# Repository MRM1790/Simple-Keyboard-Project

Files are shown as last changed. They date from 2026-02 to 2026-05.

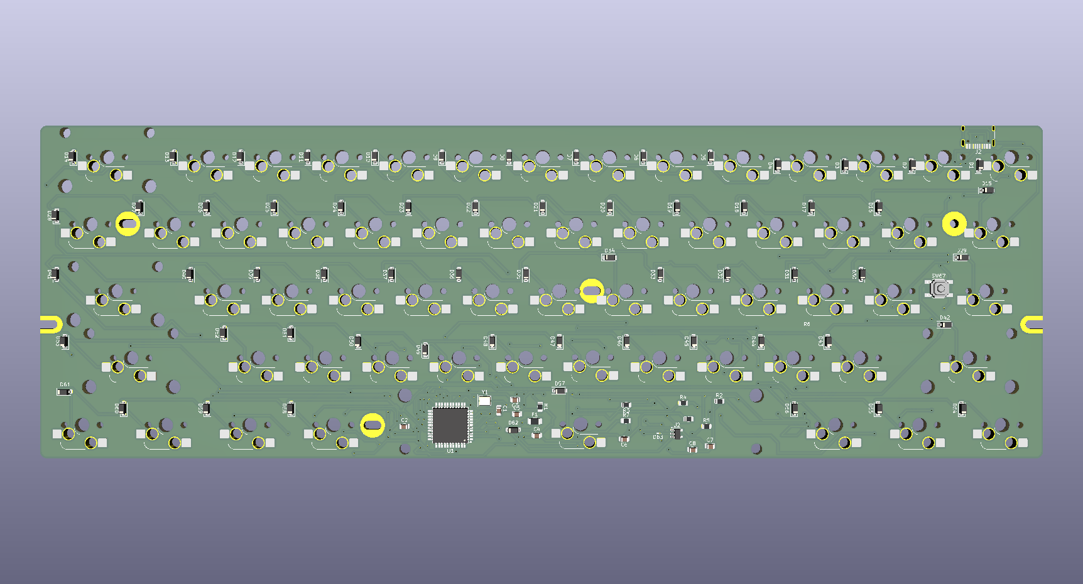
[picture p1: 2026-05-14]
Jam1_Bottom Panel.png

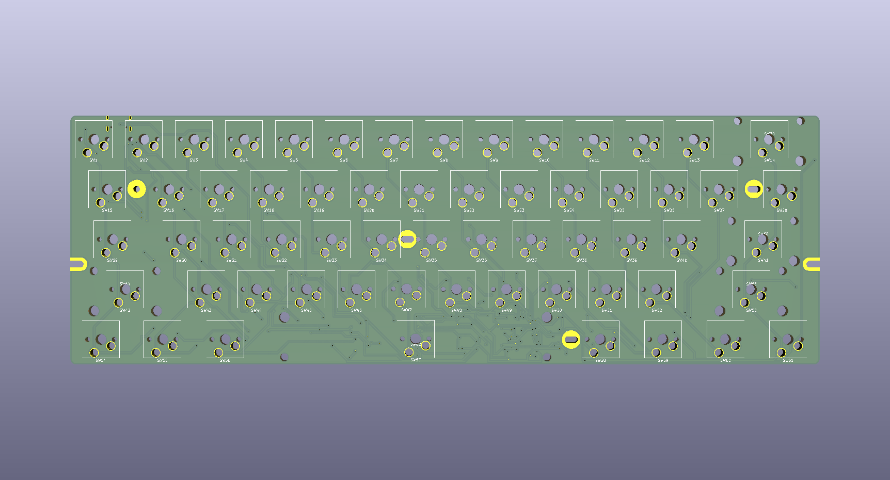
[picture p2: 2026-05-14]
Jam1_Top Panel.png

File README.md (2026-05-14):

# Simple-Keyboard-Project
DIY keyboard from scratch for school projects.
This block diagram displays what parts are considered using in this project. As the following goes, Key switches (Kailh or cherry MX) it is possible to use Choc switches (boxed switches) but for now we are sticking to kailh or cherry mx switches. We are using 3 pin switches for this project. For proof of concept, we have thought about doing a cardboard box with a "WSAD" arrow keys for now. Eventually we will do a full 74 keyboard switches. Microcontroller we plan on using is an Arduino pro micro controller that has a USB C connection for the wire to be connected to the computer or laptop. The goal is to have a keyboard matrix which are key switches that have diodes and wires soldered on each other to create columns and rows to utilize more of the pins that are on the Arduino Pro Microcontroller.  Once that is set up then the user should be able to press a input on the proof of concept model and should display either numbers or letters to the output display monitor.

ATTENTION:
  For the BOM files, designators, and CPL we recommended ordering through JLC PCB since it is configured in their version of excel and ordering process.
  QMK Toolbox will be needed to upload the code in the circuit board which a link will be provided here
  https://qmk.fm/toolbox

ATTENTION: THE SOFTWARE FOR THE KEYBOARD IS LABELED AS BOTH "KEYBOARD.JSON" AND "KEYMAP C" AND THE MAIN THING THAT YOU WILL NEED IS THE FILE THAT SAYS "jam61_default.HEX" then you will plug that into the QMK Toolbox application, and press the reset button on the circuit board in order to flash it. Once you hit the reset button in Toolbox hit flash prompt and the Hex file will go into the circuit.

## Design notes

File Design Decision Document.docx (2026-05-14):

Design Decision Document

ECET 230-002

Joshua Arriola & Maynor Roldan-Marin

When our professor first announced the project, we had to pair up and pitch two product ideas for this class. One idea was a battery pack, and the other idea was a custom keyboard. We went with a custom keyboard idea, so we needed to learn how to design a keyboard from scratch, since we were still learning how to develop and what materials were needed. The first thing we needed to do was identify the components that make up a keyboard. So one of us actually reverse-engineered a keyboard model that the other had lying around. The keyboard model was a glorious tenkeyless model, which looks like this.

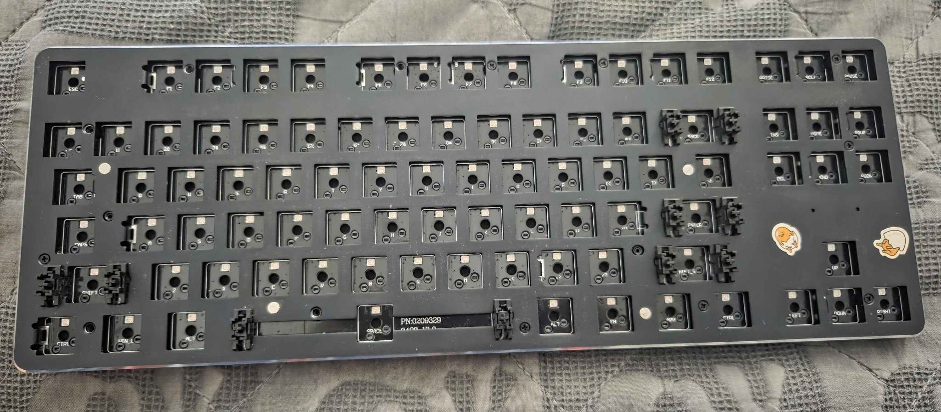
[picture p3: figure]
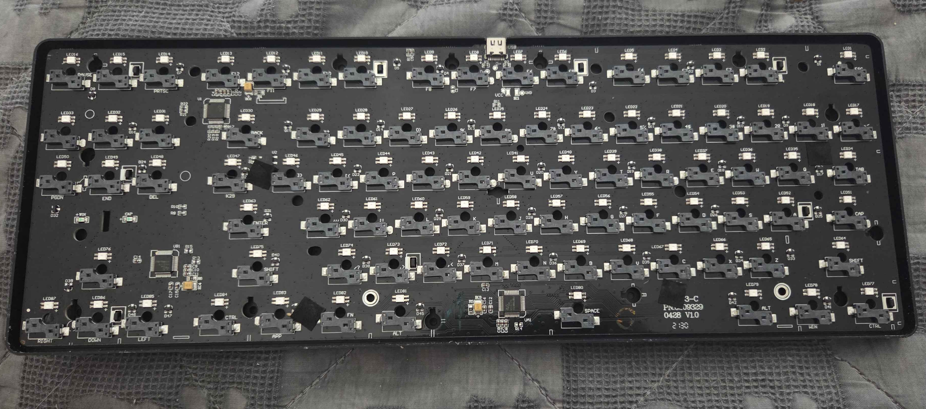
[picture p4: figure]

Once we took apart the circuit board, we noticed that this keyboard is comprised of 88 key switch sockets, 88 LEDS, 88 diodes, 3 microcontrollers, a couple of capacitors for each microcontroller, a couple of resistors, 3 encoders, and 3 SMT microcontrollers (basically a 32-bit controller, but this model has 3). After reviewing which parts this keyboard used, we wanted to implement something similar to this model's design but make it different, since the point of the project is to create a custom PCB.

So in our model, we decided to skip out on the LEDS and Bluetooth connection since that would take more time to understand schematic wise, we opted for a wired connection instead for fast inputs and a strong connection. We also decided to go with a 61-key switch version instead of an 88-key version to save time and money, since manufacturing a keyboard can take a lot of time and money. The first thing we needed to do was create a proof of concept, so we made a two-switch keyboard out of a small cardboard box to see if it was possible using an Arduino Pro Micro board and soldering some wires. Surprisingly, it worked, so we proceeded to the next phase, which was deciding what it would look like.

So we need a shell first, which holds the circuit in place, protects it from debris, and allows the circuit board to be held in place. We went with an Adafruit keyboard shell model GH60, a 60 percent keyboard that fits up to 61 keys, which was what we were looking for since we wanted to build a small, simple keyboard. While we waited for the keyboard case to arrive after ordering, we began deciding how to construct this circuit board. A keyboard matrix was needed to define the wires and connections to the microcontroller we were using, so we needed 5 rows and 14 columns of wires in KiCad. A keyboard matrix is a grid of wires organized in rows and columns.

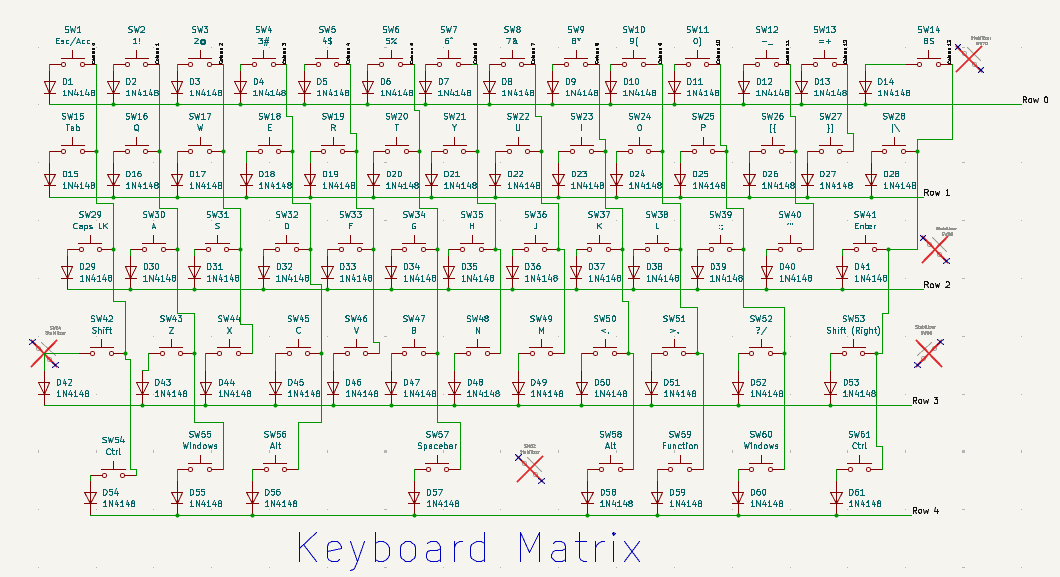
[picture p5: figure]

Then we needed to establish which rows are 0-4 (technically, rows 1 to 5) and which columns are 0-13 (technically, columns 1 to 14). Then we needed to pick a microcontroller. For context, we were told not to use a Raspberry Pi, so after asking around in the Discord community and work acquaintances, we were told that an Atmega32U4 would be used since it would be attached directly to the circuit board ourselves. The Atmega needed power from 2.7 to 5.5 volts to power on. What we tried to do was attach a voltage regulator to make sure it cuts power down to at least 3.3 volts or somewhere around that.

We also had to make sure the connection supported USB-C, since USB-C is very common nowadays, and the keyboard needed to be hot-swappable (changing components while the device is on or off) to replace keyswitches and keycaps. We also needed to ensure the sockets could accommodate 5 pins instead of 3. The reason is that many keyswitch models have 5-pin legs (3 are plastic and 2 are metal). One of us mentioned that we should have the sockets accommodate 5 pins, because if our circuit board only allowed 3 pins, you would need pliers to remove two legs of the keyswitch to make it fit inside the circuit board. So we had to use a keyswitch model that would allow 5 pins; it will still work if the switch is 3 pins too. The sockets also needed to match the switches' orientation because, when we were assembling them on the schematic, we noticed the sockets were not facing the correct positions. For example, a normal switch has one pin on the bottom left and one on the upper right; the footprint we used in KiCad showed the opposite.

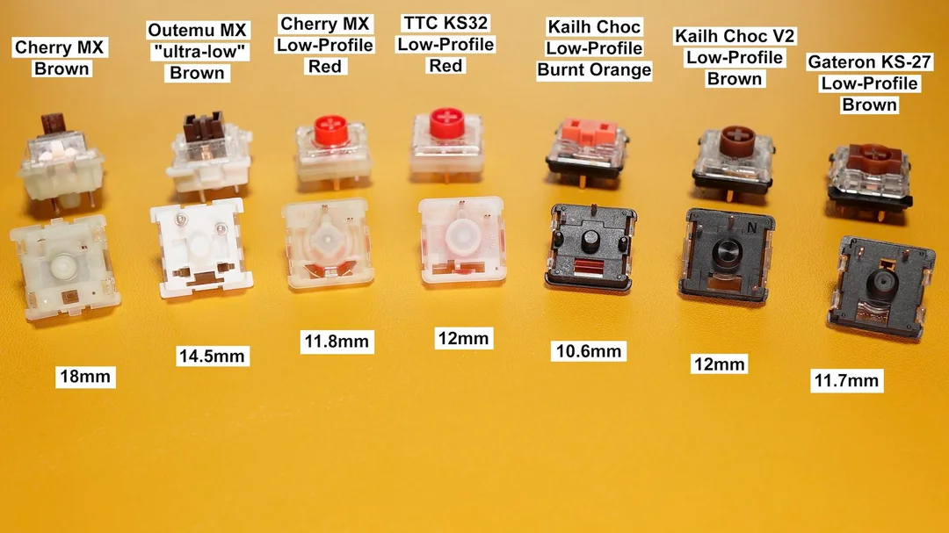
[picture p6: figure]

We wanted to ensure that the circuit uses only Cherry MX Brown switches (cherry mx brown photo). Going back to the USB-C connection, since it is type C, we needed to implement resistors for pull-downs and add data plus and minus wires to the USB-C model to get it to work with the microcontroller. The microcontroller needed many components to come to life. We needed a crystal oscillator that divided the power between the two capacitors it’s attached to to ensure a stable connection. It needed a reset switch to install firmware, new or old, and a capacitor for Ucap (external connection pin to allow the microcontroller to run at 5 volts). Pins needed to connect to the corresponding rows and columns (PB0-PB3 and PB6 are the rows and columns identified as PB4-PB5, PD0-7, PF0-PF5). There was a voltage regulator that was supposed to be attached to the microcontroller, but we made a mistake and forgot to connect it; it still works regardless (we will update that later).

The next part, which is still a work in progress, was coding, similar to what we did for our POC, we needed to establish rows and columns. Since we now have more rows and columns to work with, we need the X-axis to show only 5 rows (0-5) and the Y-axis to show only 14 columns (0-13). A key point is that one is recognized as zero, so each code needs to start at zero. First, we needed to create a JSON file by using QMK MSYS. This program allows us to create a keyboard layout from scratch. We needed to type the command “QMK compile,” then tell the program it is a pro micro chip and a new custom layout. Once it recognizes that we need a layout, it will provide us with a default layout to which we can change to match our keyboard matrix that we created in KiCad. The main reason we are using QMK is that it allows the software to configure and map keyboard codes to specific points on the circuit board. Once the JSON file knows that we need 5 rows and 14 columns, we need to map keycodes to specific points in the circuit to act as a proper keyboard (basically 0,1 = number key 1, and 0,2 = number key 2). This is very necessary for the microcontroller, since its main job is to scan the matrix for signals and display the output.

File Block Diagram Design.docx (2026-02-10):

Pressing Switches

(User Input)

Output Show Letter & Numbers

Input type

Display

(TV or Monitor)

Computer

Stabilizers

Key Switches

(kailh or cherryMX)

Hot Swap Sockets

(kailh)

PCB

Wired

(C-C/C-A)

USB Host

(5V)

Resistors

(maybe)

Capacitors

(maybe)

Diodes

(74)

Microcontroller

Block Diagram

Joshua Arriola & Maynor Roldan-Marin

Shell

Key plate

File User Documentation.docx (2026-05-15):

User Documentation

ECET 230-002

Joshua Arriola & Maynor Roldan-Marin

Description of the product: This 281mm x 95mm circuit board is designed as a computer keyboard. The product is a 61-key switch keyboard that allows you to type words, letters, and symbols via a wired USB-C connection. This is also known as a 60 percent keyboard layout, meaning it contains only numbers and letters and uses 61 key switches. What's different about this product compared to a normal keyboard is that it allows the user to fully customize it to their preferences, both appearance-wise and function-wise. This circuit is equipped with an Atmega32U4, a microcontroller that scans a wire grid composed of rows and columns.

This circuit board is also equipped with a usb c port for power and 61 hot-swappable key sockets. The key sockets are crucial because they allow the key switches to be removed and replaced with different models if the user has damaged them or wants to change them. (shown in the picture below).

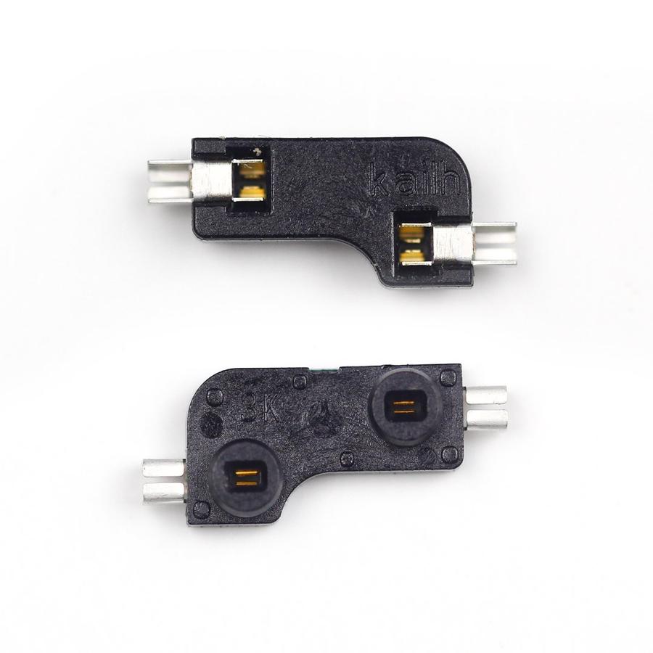
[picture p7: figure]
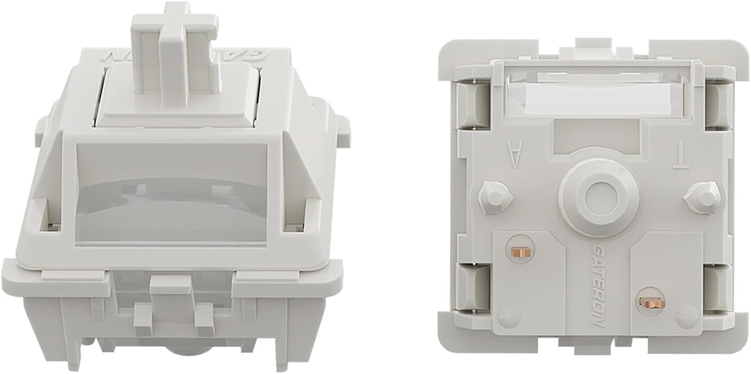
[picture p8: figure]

These allow the circuit board to be typed on by sending small jolts of electricity to the traces on the circuit, which the microcontroller senses. Once the microcontroller detects a signal from a specific position where the key switch is pressed, it will display a letter, number, or symbol. The way the switches are inserted (the picture on the left) is to grab the switch, line it up with the brass legs and the holes in the socket (the picture on the right), and slide the pins into the holes where you see the copper folds. Once slid in, these should stay in place and function as you type. One thing to note, though, is that some PCB manufacturing companies will actually solder the sockets onto the circuit board for you. If you would like to install them yourself, the next paragraph will give a brief explanation.

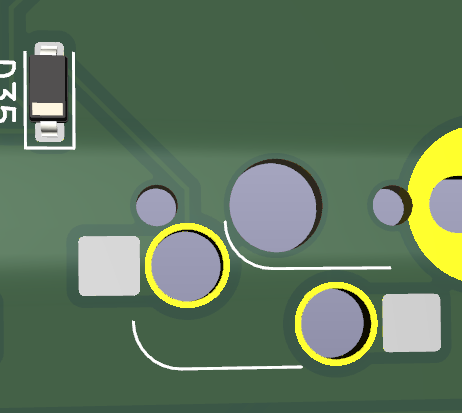
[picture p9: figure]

The picture above shows a 3D model of where the socket would go. If you look at the previous picture on the right, you will notice that the socket has two holes and two steel legs. To insert these, simply have the holes on the socket face down and the steel legs touching the square silver pad shown in the photo, which should turn out like this. The socket holes should align with the outline, and the legs should contact the square pads. Next, grab a soldering iron and some soldering wire, and add a bit of solder to the pads so it melts into the legs, soldering them directly to the board. If you flip the board, it should look like this (the second photo at the bottom).

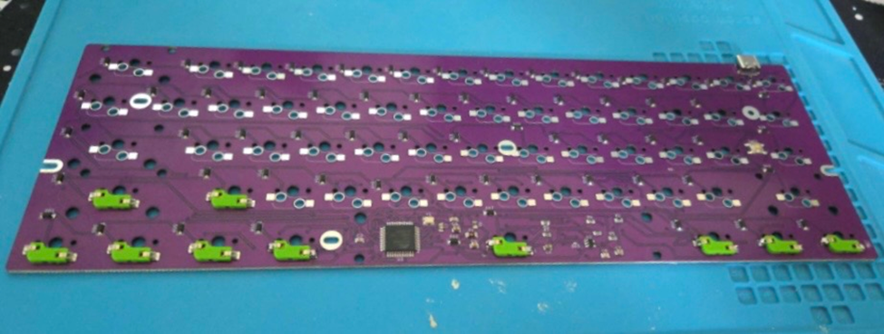
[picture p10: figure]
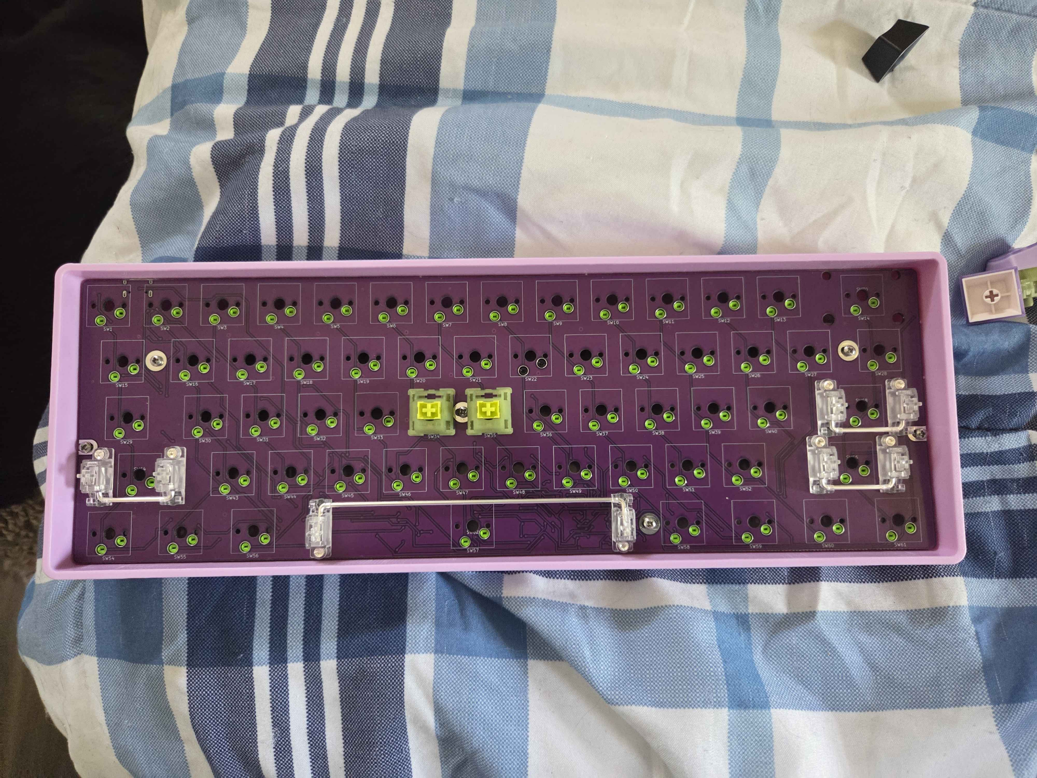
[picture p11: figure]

For this circuit board, you are going to want a shell or casing to hold the circuit board in place, and you will need exactly 61 mechanical key switches (either 3-pin or 5 models are fine, it will accommodate for either or). Key caps are also a must if you do not want to press the key switches directly. Key caps and key switches are largely a matter of user preference. A good starter for key switches would be generic Cherry MX Browns if you are on a budget.

Does it work right out of the box? The answer is no, you will need to install the coding firmware on this. If you flip the back of the board all the way to the left, you will see a hexagonal button that serves as a reset button, resetting the circuit board to allow firmware to be installed. The way you do that is by using QMK Toolbox (available on GitHub or Google; the link is below). Once you have downloaded the software to the computer, you will need the code, which will be in our GitHub repository (another link will be provided). After you have those two, grab your circuit board and a USB-C wire and connect it to the USB-C port on the circuit board.

Once you have connected them, launch QMK Toolbox first, then click the Open tab and find the code you downloaded. It should be labeled as “Jam61_default.Hex.” If you have not already hit the reset button on the circuit board and clicked the command that says “flash,” this should then install the code into the device.

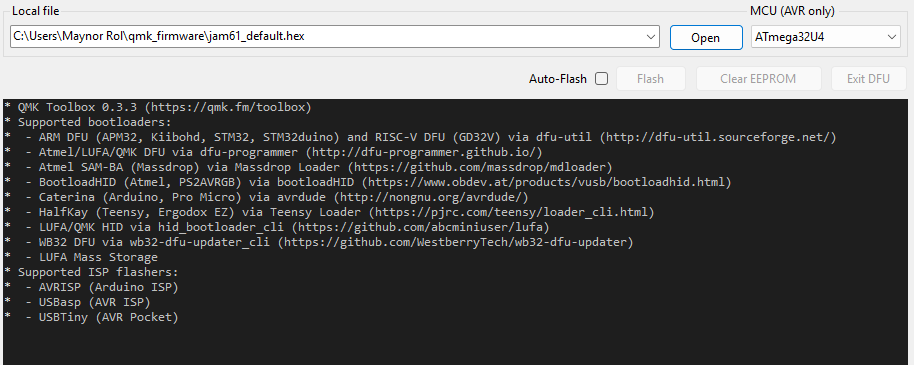
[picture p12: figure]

Once this is complete, it will say "flash complete," and you should be able to type on it. If you wish to test it out, there’s a tab that says tools, click it, and you’ll see the prompt “Key Tester,” and you should see your keyboard show displays and inputs. https://qmk.fm/toolbox (QMK TOOLBOX link)

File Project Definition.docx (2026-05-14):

Project Definition

ECET 230-002

Joshua Arriola & Maynor Roldan-Marin

Description:

- Custom Keyboard (Project: JAM)
- Creating a PCB that has keyswitch hot swappable sockets where users can customize or modify switches or change keycaps without having to hire an expert.

Purpose:

- Allows the user to change how the keyboard feels and sounds to their preference, such as clicky keyswitches with loud typing to silent typing and a soft feeling of the keyswitch.
- The purpose of this product is to allow users to switch keycaps and keyswitches without having to desolder switches from the PCB. The idea is to create a hot swappable PCB to easily take out the keycaps and keyswitches without having to open up the keyboard entirely.

Communication:

- Using Google Docs along with repositories from GitHub to see what changes were added and what was removed from the designs. This will allow communication among peers.

Objective:

- Create a keyboard PCB (Printed Circuit Board) that is user friendly, and allows easy modifications without having to open the keyboard entirely.
- Create a reasonable-sized keyboard that is able to fit inside backpacks and has measurements of 14”x4-1/4”x1” (Length by Width by Height).

User Interaction Scenario:

- Configuration should be working out of the box; the user would only need to plug in the computer. If they wish to make any adjustments, they can use the QMK firmware to change the functionality of their liking. Which will be provided with a website link for access.
- Main usage can vary; this could be used for those who work in office spaces or those who want to use it for computer games.
- Users would need a 2 in 1 keycap puller and switch puller to change their keyswitches and keycaps if they don’t like the current set-up.

User Interface:

- There needs to be a small LED to signal to the user that their keyboard is fully activated and is linked to their device. Either we can have an audio cue from the device play when the keyboard is plugged in, or have a small transparent circle near the microcontroller to show that the circuit board is functional.
- Show display monitor the letters and numbers that the user types.
- The keyswitches will need to be pressed by the user to show the inputs that they have typed in.

Operational:

- Using wired connection to reduce the amount of input latency.
- Duty varies on what the keyboard is being used for such as computer keyboard, business corporations that use applications such as word docs, excel, etc.

Environment:

- Temperatures could produce ESD (A.K.A static shock) if the PCB is not installed in a good material case. Recommended to use aluminum or PLA casing
- Power, would recommend using wired connection for low latency and direct connection to computers or devices. Recommend using braided nylon cord specifically type C or Type C to A. This helps prevent static shock.

Key Concerns

- Main concern would be the PCB to be customizable and hot swappable.
- Good and responsive inputs with the keyboard.
- Assigning additional commands via button combinations.
- Reasonable size keyboards to fit in backpacks.
- Using the LED to signal to the user that the device is active.
- Must be Wired Connection, bluetooth could cause more potential problems.
- Needs to be USB C to C or USB C to A.

Project Definition Updated Version

ECET 230-002

Maynor Roldan-Marin & Joshua Arriola

Throughout the project, we needed to make some changes here and there to align with the vision we had for the computer keyboard. The main things we needed to change are as follows. The reasons for the changes were time constraints and budget constraints, since manufacturing a keyboard can be really expensive, depending on what is needed and what fits the project's budget.

Description & Purpose: As previously discussed, our circuit board needed to be a custom keyboard fully customizable to the user's preferences. The user should be allowed to change the keycaps and key switches that they want to use, so we devised a plan to add hot-swappable key sockets to be implemented into the board so that the user can freely use a 2-in-1 keycap puller to remove both the key switch and keycap freely without having to hire an expert to work on their keyboard. We were able to implement the key sockets on the PCB by soldering them directly to the board, since the manufacturer ran out of stock and we needed to improvise to keep the “fully customizable” part of the project. This project depends on those hot-swap sockets to prevent the user from having to hand-solder switches directly into the board or from having to find someone to do it for them. If people are going to order from PCB manufacturing companies, we wanted to make sure to include the hot-swap sockets in the BOM files so they can do it for them if users don’t want to solder sockets to each pad.

Objectives: For the objectives, we needed to change the dimensions of our keyboard project. We intended the keyboard to be 355.6mm by 107.95mm (14”x4-¼ inches). We decided to go for a smaller model and settled on a circuit board measuring 281mm by 95.0mm (11.063 by 3.740 inches). We decided to change the dimensions because we asked students in our classroom whether they preferred a larger or a smaller keyboard. One student stated that, personally, they wouldn’t use a keyboard due to the limited desk space they have at home, so we wanted to accommodate that. Another objective that hasn’t changed is that the keyboard needed to fit inside a personal bag with ease, so there are no issues transporting it or making space for the user's personal bag. We were able to keep the customization we wanted, so we were still able to customize keycaps and switches.

User Interaction Scenario: The main usages we intended for this keyboard to be used in offices, schools, and at home. We were able to make the keyboard small enough for transportation and switch between silent and tactile switches (bump feeling and a bit loud). As stated previously, we needed a two-in-one keycap puller (a tool that allows the removal of both keycaps and key switches). However, when it came to the out-of-the-box experience, we learned that, realistically, it would be a bit difficult because the user would need to upload the code and firmware to the keyboard. So realistically, we need to do a different approach; we decided to configure the code and upload it to the GitHub repository we created for this project. The user would need the HEX code and the QMK Toolbox application to download the code to the PCB. In a brief explanation, connect a USB-C wire to the USB-C port that is located on the upper left corner of the board. Then find the HEX code and press the flash button after clicking the reset button on the board.

User Interface: For the user interface, we completed 5 of the 6 items we listed. Due to time and budget constraints, we removed LEDs from our circuit board. Our original design was to have LEDs on our board to signal to the user that the circuit board is connected and powered on, but we ended up having the circuit board play an audio cue on the device the user connects to. If we added on LEDs, there was a chance that the manufacturing company we paid would put too much heat on the SMD LEDs and would possibly cause burnout during production (basically, plug in the keyboard and only see a certain amount of RGB LEDs turn on instead of all of them being lit up). We were able to get the connection correct: USB-C to A or USB-C to C. The keyboard can display outputs on the display when a key is pressed, and the board can scan and output the user's typing on the switches.

Dependencies: The circuit board required traces for most components: diodes, capacitors, the microcontroller chip, hot-swap sockets, and the crystal oscillator. We heavily relied on diodes, hotswap sockets, the microcontroller of choice, and USB-C. Diodes and the hotswap sockets depend on each other: the sockets allow the keyswitches to be inserted and pressed, and the diodes prevent backflow of electricity. A microcontroller is needed to scan the keyboard matrix we created so it can pinpoint where a key is being pressed and communicate to the USB-C connection that a key is being pressed. We used resistors on both the controller and the USB-C port to ensure a stable connection to the computer or device.

Key Concerns: For our main concerns, we completed 5 of the 6 goals we set; the one we left out was LEDs due to the potential risk of LEDs being dead on arrival from the manufacturer, and the delay in replacing them would delay production. We were able to reduce the keyboard's size and fit it in a personal bag. It emits an audio cue when plugging the keyboard into a device. We assigned two layers: a base layer that does normal commands, and a function layer that does extra commands via a button combination. If you press the FN key and either W or D, for example, it will enter arrow key mode. Once you let go of the function key, it will return to normal. It has responsive inputs and performs as intended. It is a wired connection, so you will need a USB-C cable to power it on and get it working.

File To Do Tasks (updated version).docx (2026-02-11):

To Do Tasks!

02/10/2026 (updated)

Joshua Arriola & Maynor Roldan-Marin

1. We need to create the proof of concept model first. Once the POC (proof of concept) is created and displayed using the microcontroller, we will have more of an idea of how to implement the ideas used into the prototype-like phase.
2. Using KiCad to create a schematic of our version of using an arduino board to make a 74 keyswitch version of the keyboard we plan to make. Once POC is done, we need to create a pcb circuit that limits the amount of wires and be able to fit the circuit into a 3D printed case for the prototype phase.
3. Once the keyboard shell is created, we need to use the QMK firmware to assign additional commands in case there happens to be any additional commands that were taken out during our keyboard design. Example given: page down is not present, so we need to map button combinations using the firmware to signal the command, like “FN+F12 = Page down”.
4. We need to implement diodes, specifically model number “1N4181” to be used for each individual keyswitch, along with voltage regular to make sure that the diodes do not get overpowered and destroyed in production.
5. The keyswitches need to have hot swap sockets, meaning that we need to implement keyswitch sockets to be able to change keyswitches without having to hire an expert. The goal is to be able to change the keyboard from functional to aesthetics to the users preferences.
6. Needs to be USB C to C or USB C to A. Most computer models or laptops only use either type C to C or type C to A. So it is necessary to have this implemented in our circuit board since type B is considered obsolete.
7. Needs to be a wired connection to prevent latency from being present, we could implement a bluetooth version but that would mean potentially connection issues. Such as delayed input responses, or failure to connect to devices.

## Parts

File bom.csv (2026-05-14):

Designator | Footprint | Quantity | Value | LCSC Part #
C1, C4, C7 | 805 | 3 | 1uF | C28323
C2, C3 | 805 | 2 | 22pF | C1804
C5, C6 | 805 | 2 | 10uF | C380332
C8 | 805 | 1 | 0.1uF | C17356222
D1, D10, D11, D12, D13, D14, D15, D16, D17, D18, D19, D2, D20, D21, D22, D23, D24, D25, D26, D27, D28, D29, D3, D30, D31, D32, D33, D34, D35, D36, D37, D38, D39, D4, D40, D41, D42, D43, D44, D45, D46, D47, D48, D49, D5, D50, D51, D52, D53, D54, D55, D56, D57, D58, D59, D6, D60, D61, D62, D7, D8, D9 | D_SOD-123 | 62 | 1N4148 | C2099
D63 | 201 | 1 | Red | C9900221497
F1 | 1206 | 1 | 500mA | C20799
J2 | USB_C_Receptacle_HRO_TYPE-C-31-M-12 | 1 | USB_C_Receptacle_USB2.0_16P | C2927036
R1, R2 | 805 | 2 | 5.1K | C27834
R3, R4 | 805 | 2 | 22ohms | C3017752
R5, R7 | 805 | 2 | 10K | C17414
R6 | 805 | 1 | 1Kohms | C2889437
SW1 | Hotswap_MX_Plated_1.00u | 1 | Esc/Acc | C2803348
SW10 | Hotswap_MX_Plated_1.00u | 1 | 9( | C2803348
SW11 | Hotswap_MX_Plated_1.00u | 1 | 0) | C2803348
SW12 | Hotswap_MX_Plated_1.00u | 1 | -_ | C2803348
SW13 | Hotswap_MX_Plated_1.00u | 1 | =+ | C2803348
SW14 | Hotswap_MX_Plated_1.00u | 1 | BS | C2803348
SW15 | Hotswap_MX_Plated_1.00u | 1 | Tab | C2803348
SW16 | Hotswap_MX_Plated_1.00u | 1 | Q | C2803348
SW17 | Hotswap_MX_Plated_1.00u | 1 | W | C2803348
SW18 | Hotswap_MX_Plated_1.00u | 1 | E | C2803348
SW19 | Hotswap_MX_Plated_1.00u | 1 | R | C2803348
SW2 | Hotswap_MX_Plated_1.00u | 1 | 1! | C2803348
SW20 | Hotswap_MX_Plated_1.00u | 1 | T | C2803348
SW21 | Hotswap_MX_Plated_1.00u | 1 | Y | C2803348
SW22 | Hotswap_MX_Plated_1.00u | 1 | U | C2803348
SW23 | Hotswap_MX_Plated_1.00u | 1 | I | C2803348
SW24 | Hotswap_MX_Plated_1.00u | 1 | O | C2803348
SW25 | Hotswap_MX_Plated_1.00u | 1 | P | C2803348
SW26 | Hotswap_MX_Plated_1.00u | 1 | [{ | C2803348
SW27 | Hotswap_MX_Plated_1.00u | 1 | }] | C2803348
SW28 | Hotswap_MX_Plated_1.00u | 1 | |\ | C2803348
SW29 | Hotswap_MX_Plated_1.00u | 1 | Caps LK | C2803348
SW3 | Hotswap_MX_Plated_1.00u | 1 | 2@ | C2803348
SW30 | Hotswap_MX_Plated_1.00u | 1 | A | C2803348
SW31 | Hotswap_MX_Plated_1.00u | 1 | S | C2803348
SW32 | Hotswap_MX_Plated_1.00u | 1 | D | C2803348
SW33 | Hotswap_MX_Plated_1.00u | 1 | F | C2803348
SW34 | Hotswap_MX_Plated_1.00u | 1 | G | C2803348
SW35 | Hotswap_MX_Plated_1.00u | 1 | H | C2803348
SW36 | Hotswap_MX_Plated_1.00u | 1 | J | C2803348
SW37 | Hotswap_MX_Plated_1.00u | 1 | K | C2803348
SW38 | Hotswap_MX_Plated_1.00u | 1 | L | C2803348
SW39 | Hotswap_MX_Plated_1.00u | 1 | :; | C2803348
SW4 | Hotswap_MX_Plated_1.00u | 1 | 3# | C2803348
SW40 | Hotswap_MX_Plated_1.00u | 1 | '" | C2803348
SW41 | Hotswap_MX_Plated_1.00u | 1 | Enter | C2803348
SW42 | Hotswap_MX_Plated_1.00u | 1 | Shift | C2803348
SW43 | Hotswap_MX_Plated_1.00u | 1 | Z | C2803348
SW44 | Hotswap_MX_Plated_1.00u | 1 | X | C2803348
SW45 | Hotswap_MX_Plated_1.00u | 1 | C | C2803348
SW46 | Hotswap_MX_Plated_1.00u | 1 | V | C2803348
SW47 | Hotswap_MX_Plated_1.00u | 1 | B | C2803348
SW48 | Hotswap_MX_Plated_1.00u | 1 | N | C2803348
SW49 | Hotswap_MX_Plated_1.00u | 1 | M | C2803348
SW5 | Hotswap_MX_Plated_1.00u | 1 | $4.00 | C2803348
SW50 | Hotswap_MX_Plated_1.00u | 1 | <. | C2803348
SW51 | Hotswap_MX_Plated_1.00u | 1 | >. | C2803348
SW52 | Hotswap_MX_Plated_1.00u | 1 | ?/ | C2803348
SW53 | Hotswap_MX_Plated_1.00u | 1 | Shift (Right) | C2803348
SW54, SW61 | Hotswap_MX_Plated_1.00u | 2 | Ctrl | C2803348
SW55, SW60 | Hotswap_MX_Plated_1.00u | 2 | Windows | C2803348
SW56, SW58 | Hotswap_MX_Plated_1.00u | 2 | Alt | C2803348
SW57 | Hotswap_MX_Plated_1.00u | 1 | Spacebar | C2803348
SW59 | Hotswap_MX_Plated_1.00u | 1 | Function | C2803348
SW6 | Hotswap_MX_Plated_1.00u | 1 | 5% | C2803348
SW67 | SW_SPST_SKQG_WithStem | 1 | Reset Switch | C2886894
SW7 | Hotswap_MX_Plated_1.00u | 1 | 6^ | C2803348
SW8 | Hotswap_MX_Plated_1.00u | 1 | 7& | C2803348
SW9 | Hotswap_MX_Plated_1.00u | 1 | 8* | C2803348
U1 | TQFP-44_10x10mm_P0.8mm | 1 | ATmega32U4-A | C44854
U2 | SOT-23-5 | 1 | MIC5219-2.5YM5 | C18212648
Y1 | Crystal_SMD_3225-4Pin_3.2x2.5mm | 1 | 16MHZ | C112972

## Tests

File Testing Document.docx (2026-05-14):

Testing Document

ECET 230-002

Maynor Roldan-Marin & Joshua Arriola

After placing an order with JLC PCB, we had to solder the hot-swappable sockets ourselves. The reason was that when we placed the order, they notified us that two parts needed to be re-ordered because they had run out of the USB-C port and the hot-swappable sockets. They were able to get us a replacement for the USB-C port, but the sockets we actually needed to find a suitable replacement ourselves and make sure they are compatible with our circuit board. We had the code written, but we needed the circuit board to fully test to see if our code would get recognized by our matrix, however time was not on our side since we happened to order the PCBs around the time of a holiday where they close down for 3 days (Labor Day in China, May 3rd - May 5th). We did not account for the possibility that our circuit might not reach us in time, but thankfully, it arrived a day before our deadline (we’ll get back to that later).

So when our circuit arrived, as stated, we needed to solder the hot-swap sockets. We could still have wired it by hand-soldering the keyswitches directly to the circuit board (basically, line up the 5 legs into the holes where the circuit is and add solder only to the metal legs of the switches), but that would defeat the purpose of our project.

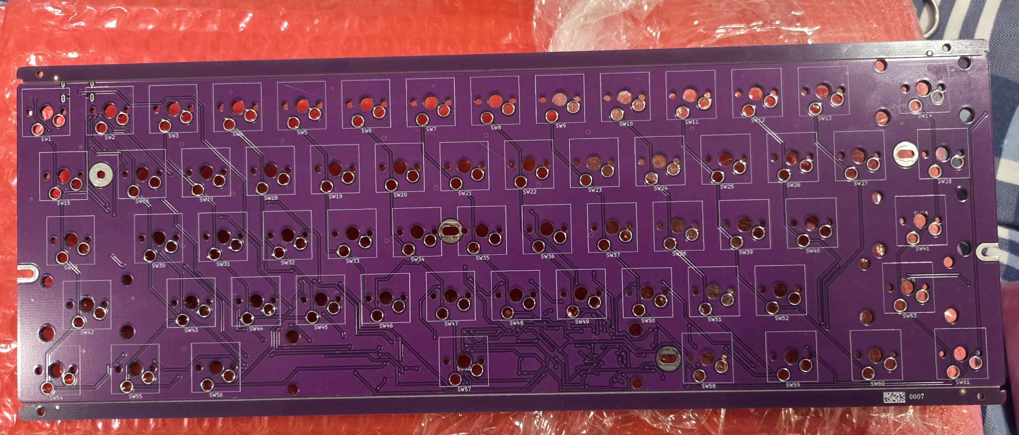
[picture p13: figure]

When we were done soldering on the sockets to the circuit board, we noticed that some of the switches were not staying in place with the sockets, at first we thought it was because it wasn’t fully soldered on, but it turned out they actually were. To fix this, we had to switch to Kailh sockets instead of the Du-rock sockets we were using. Once that was soldered on, we needed to see if the circuit would even power on and get recognized by one of our computers, so we grabbed a USB-C wire and plugged it into the circuit. To our surprise, the circuit powered on and made an audio cue on the computer to signal that the device is connected. We tested the connection by physically removing and reinserting the wire into USB port 5 5 times to ensure it could power off and on without short-circuiting. Then we tested the reset switch by pressing the button on the back of the circuit, and it reset the computer as intended. We also did this when we installed it in the case we ordered, which has a hole to press the reset switch with a pencil or something narrow.

The next step was to connect the switches to each socket and turn it upside down to see if any switches would fall out on its own. If they fall out, the sockets would need to be replaced with more sturdy ones, and the keyswitches would need to be reinserted as the device is powered on. After that, we installed the code by flashing firmware into the circuit, then hit reset; it then gets set to factory boot loader mode. We upload the files, press some keys on the keyboard, and see which switches register and what don’t. This was a strange part of the testing because we discovered that some of the keys were mapped or flipped to different parts of the keyboard. For example, the letter P would display a number instead of a letter.

The first issue we assumed was the keycodes mapping, which turned out to be correct; some of the keycodes were mapped to different keys. Which was not intended, so we had to flip them back to their proper keycodes; however, not all the keys cooperated in returning to their proper key mapping. So we had to do trial and error by flashing and re-flashing the firmware each time we caught a mistake or managed to fix a part in our coding. Once reflashed, we pressed a key to see if it produced an output. As of now, 55 keys work properly, but we are still trying to figure out where in our coding did the last remaining 6 keys went. We had a theory that, since our layout is not traditional, it may be related to how our keyboard matrix is mapped, or to our rows and columns in Visual Source Code. For now, it functions as intended, but we’re still working on the last 6 keys needed.

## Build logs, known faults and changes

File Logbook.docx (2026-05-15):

Logbook

ECET 230-002

Maynor Roldan-Marin & Joshua Arriola

Journal Entry #1 POC concept design process:

To begin our journey to creating a custom circuit board. We were told in class to first create a proof-of-concept device to show that what we wanted to create is indeed possible, either using breadboards or developer microboards. Our professor suggested starting small by using a piece of cardboard or a box from a store product, which got us thinking about whether people had done that before. To both of our surprise, yes, many people have actually first started off doing that. We had to do some research to figure out how to create a POC (proof of concept), so we searched YouTube and online communities to get an idea of how to create one.

During our search, we learned from two internet influencers which dev board we should use to build our concept. The two influencers were Joe Scotto and another influencer who goes by the nickname Djambo (his full name is not disclosed on YouTube or GitHub). In both of their YouTube channels, they should use a method called hand soldering. Which is grabbing some diodes, some keyswitches, some silicone wires, a soldering pen, and lastly a dev board. The dev board that was featured in both videos was a model called “Arduino Pro Micro,” which operates at 5 volts and 16MHz (megahertz). What we learned was that by soldering a diode and wire to a keyswitch of our choosing, we were creating a physical keyboard matrix (a grid of rows and columns made by wires where a keyswitch is placed in the middle of certain points of the grid).

Once we learned how to create a physical keyboard matrix, we decided to create two types: a 2-key switch prototype and a 16-key switch prototype. Once we had constructed those, we needed to learn how to code the command inputs and install the code on the dev board. The reason is that those boards do not work out of the box. We actually needed to go through a bit of a process to get to the code sent to the dev board, using 3 applications. The applications were Visual Source Code (coding and mapping keycodes), QMK MSYS (allows us to create a new keyboard layout instead of using presets), and lastly QMK Tool Box (to flash and configure the key mapping on the device we made). The 16-key version actually failed due to faulty hardware, as it compiled and was sent to the dev board; however, the 2-key switch model was a success.

Journal Entry #2 Designing The Keyboard In Kicad Schematic:

Moving forward with the design process, we were being told to start creating our schematic. As soon as we finished our presentations about our POCs, we decided to get started early on the design of the actual keyboard circuit. Our professor advised everyone to begin working on KiCad schematics. We were not sure exactly when the schematics would be due, but we also had to focus on other classes. One of us started looking into the components we would need, and another would create mock-up designs (different versions of the keyboards) while we gathered more info on how to create a custom circuit board from scratch. We wanted to use a Raspberry Pi, but we were told not to, so we need to search for alternatives.

We went through about 5 different schematic versions of the keyboard design because the first version used a Raspberry Pi, which we were not permitted to use. The second version had a dev board that was also not allowed to be used, and the 3rd had the correct chip we needed, but the hot-swappable sockets were not the correct versions we needed (more on that later). The 4th version was missing a part that we needed, which was the USB-C pull-downs, and not enough pins for the previous microcontroller we picked out. The 5th version was the one we settled on after many edits and additions to make it compatible with the objectives we set for ourselves.

Journal Entry #3 Creating an actual circuit board on PCB editor mode:

When the schematic was complete, we forgot to get the correct footprint models for our keyboard project. We realized that KiCad’s footprint library did not contain all the required footprints, so we first needed to retrieve them from GitHub. After asking some resources, such as colleagues and people in the QMK Discord community, they pointed us to GitHub mechanical keyboard footprints and symbols. The footprints we needed were: Hot-swappable MX-plated keys and MX stabilizers. Mainly, we needed the footprint “Hotswappable MX plated” because we needed 5 holes and a square outline for each key switch to be inserted, along with sockets installed on the back of the device.

Once we had all the correct footprints and components set in the schematic and PCB editor mode. One of us needed to order physical materials unrelated to KiCad, while the other worked on different versions of the PCB editor. One of us realized that we did not have a template outline for the keyboard we were building. The issue was that when we bought the shell casing for our keyboard, we assumed they would provide an instruction manual with the casing dimensions and the dimensions of the screw holes, but we never received one. So we needed to once again ask for advice on where to find the outline template for this keyboard, because if we were to do exact measures of the casing, then the circuit board would not be able to be inserted in the case, because there would not be any clearance for us to mount it inside the shell casing.

Once we had contained the outline through GitHub by the user “Komar007” (yes, that is his username). We were able to include the correct outline templates, along with the correct dimensions and measurements, to ensure it fits nicely in the case. Then we began editing the PCB and some routing. This took us a bit of time to do because, as we were routing, we noticed that some traces needed to be redone or removed entirely due to short-circuiting or being too close to the stabilizer mounting holes or mounting screw holes. We needed a 2-layer circuit board because anything more than 2 layers would be too thick to mount on the case pillars, where it gets screwed on. So we need to ensure three things. The first one was ensuring that we stick to two layers of copper on the circuit board; the second was ensuring that the microcontroller was in a good place so the necessary components were close by for wiring; and the third was ensuring that all the parts needed were on the bottom of the circuit board. Once all of this was assured, we began routing everything together, which took us seven different edits.

Journal Entry #4 Finding a PCB manufacturing company:

After we were satisfied with the model, we decided to go the extra mile and actually ordered 1 batch of 5 boards. We checked companies like Oshpark, JLCPCB, PCBway, and Digikey to see if any of them could actually create the circuit board for us, since we were short on time and wouldn’t have time to place the SMD components ourselves due to our other classes. We had some issues getting the BOM files to work until one of us figured out we needed to download an extension file that converts the BOM (bill of materials) into the format JLC accepts. However, we were not done with the issue. We then needed to find the exact part numbers and designators for JLC to gather and put together for us, which took us more time to dig into.

Once that was done, there were some back-and-forth calls with the representative who was assigned to us. Our board was scheduled to come in on May 8th, which was the day our presentation was supposed to take place. What happened was that we happened to order the boards at a horrible time because May 3rd through May 5th is a holiday in their region. Miraculously, the boards arrived a day before presentation day, but we needed to buy the hotswap sockets ourselves because JLC happened to be out of stock. We went to Amazon, bought the parts, and decided to solder them onto the circuit board ourselves to save some time. Then, when we received the sockets and soldered them onto the board, we were ready to begin coding and mapping 61 key codes to the keyboard circuit. Which was more trouble than we initially thought.

Journal Entry #5 Physical Assembly and Coding Of The Product:

At this point, we were in the final stages of the project, once we received the circuit and inspected it to see if it had survived packaging and mail carrier transportation. So we first did some coding to map the key codes to the keyboard's key switches while we waited for the board to arrive. We first had to resolve the key socket issue, so we soldered those onto the board, then populated all the sockets with the keyswitch we picked for our project. Afterward, we launched QMK Toolbox, grabbed the hex codes, and installed them on the board by pressing the reset button. Then, clicking the flash prompt in the QMK toolbox; however, this was not smooth sailing from here, because somehow all the key mappings were randomized on our keyboard.

There were ups and downs. The upside was that we had confirmation that the device we made in KiCad actually works, but the downside was that we needed to go back into the code and figure out where the matrix maps everything. After hours of trial and error, we were able to map 54 of the 61 keys on our keyboard. We were running out of time because our project presentation was on Friday, May 8th, and our board arrived the day before, so we were on borrowed time. Then another scenario happened that was completely out of our control: the Canvas hacker group took NJIT hostage for a bit, so finals were pushed back. It did give us more time to work on the coding, but we still couldn't figure out how to get the other 6 keys working properly due to other class finals and projects. We did, however, assemble it fully so it would look neat during the presentation. Hopefully, we’ll be able to figure out how to get the remaining 6 keys to work, since we are near 100% functionality. At the moment, the project is 95% functional.

Journal Entry #6 What Did We Learn?:

So what did we learn? Well, to get it out of our systems, creating a keyboard is very difficult. Creating a keyboard requires both time and focus to get everything together properly. For example, when we first started off, we picked a random Atmega chipset for our project, not realizing that there were not enough pins to accommodate 14 columns and 5 rows, so we had to go with a chipset which was Atmega32u4 which contain just enough pins for everything that needed to be wired up. The other thing we learned was that USB-C required pull-down resistors and Data pins connected to the microcontroller; otherwise, it would not communicate with the device it was plugged into. Then we needed a reset button and more resistors. Without the reset button, users would need to use conductive tweezers to short-circuit the board to force it into bootloader mode. To make it easier for people, we added a reset switch in PCB editor mode with the footprint model.

The other thing we learned was that routing can be very tricky, and that certain components need to be a certain length to ensure that connections are not interfered with; otherwise, it would not work as intended. Then there was the voltage divider, so we made a small mistake when we created the voltage divider, which was very simple… we forgot to connect it to the microcontroller. So initially, we planned to limit the input voltage to 3.3 volts because our microcontroller only needs 2.7 to 5.5 volts to power on. We wanted to play it safe and limit the voltage, but forgot to connect it to the microcontroller. It still works as intended, so there were not many issues there. Finding a company to actually produce the physical hardware, though, was very tedious.

When we contacted a company that would get it to us on short notice, we needed to submit a BOM file in their format. For some reason, it had to be laid out in a specific Excel sheet for the machine they were using to get precise measurements and the correct components needed for this project. Each time they did not have a part we needed, we had to find substitutes so they could start production; for example, the USB-C port. We apparently forgot to add sink-mount holes for it, so we changed the model to be purely SMD (surface-mount device). We had to communicate with them to change the part that was interfering with production. We also learned not to order specific weeks from them because when we made orders with JLC, it happened to be Labor Day in their region, which delayed shipping and packaging to the United States.

Conclusion:

This project allowed us to see how companies and small electronics shops create their keyboard products. From the thought process to how to accommodate certain user wants and needs. It also gave us a lot of insight into making different versions of a keyboard matrix and how to go about creating one. This project was worked on from January 20th to May 15th (a 4-month span). In all honesty, we are both surprised that this circuit powered on and registered inputs; there is still work that could be done to make it much better. Due to time constraints, however, with the semester we had to settle for the project being 95 percent done because 6 keys were not functioning as intended. We theorized that somewhere in the JSON file's matrix coding, our last column had been cut off, but that would take more time to inspect every aspect of the coding. If there had been more time in the semester, we probably would have been able to get it fully functional. We would like to return to this project over the summer and possibly create newer, improved versions of the circuit board. This project was very insightful if we ever decide to enter the computer peripherals business.

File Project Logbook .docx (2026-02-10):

Keyboard Project: ECET 230-002 Log Book

(still in progress)

By Joshua Arriola & Maynor Roldan-Marin

The project that we chose to do is a handmade keyboard. The idea came from past projects done by others and the current rise of DIY (do it yourself) online video content. This can vary from the selection of keyswitches, keyboard shells, and aesthetics. Instead of buying a pre-built keyboard, there is nowadays an option to custom-tailor a keyboard to a person’s liking. From the keyswitches, to keycaps, the color of the shell, the material of the shell, and the type of printed circuit board, and the types of microcontroller that is being used. The manufacturing of a person’s keyboard can also be selected from a vast amount of methods, such as breakout boards or hand-soldering wires to a microcontroller, such as raspberry pi or arduino microcontrollers. For the proof of concept, we opted to make two small cardboard boxes to show that it is possible to build a very simple keyboard with just cardboard, and then eventually, when that phase is done to give the keyboard a proper shell and materials.

How to go about the design and component choices? The first order of business was to construct a block diagram design that shows us what could and what will be necessary to have for this project. The components listed in the diagram for the first part which is the POC (Proof of Concept) is as follows: Keyswitches, microcontroller, 28 gauge wires, and diodes. For the POC, we opted to create a keyboard matrix and paired it up with an arduino micro controller, for now, the goal is to have 2 or 4 keyswitches wired up and solder on a breadboard while attached to this microcontroller. As shown through the schematic found through a youtuber influencer named “Djambo”, which displays the pins and layout of where each column and row that will be utilized to communicate with a firmware called “QMK”. Hypothetically, the firmware should allow the user to press a keyswitch which will communicate with the firmware installed into the arduino that a letter or number needs to be displayed to the computer or laptop. The schematics that Djambo shows is a macro keyboard that is using 20 switches and is attached with diodes for each switch.

The schematic displays that each switch will have wires and diodes soldered into each other for each keyswitch and diode. While 28 gauge wires will be sticking outside of the matrix to be soldered into the arduino pins, so the board can recognize which column is plugged and which row belongs to each column that is wired up. The diodes listed are model number 1N4148 which was used for this model that Djambo created, so we will implement this design for the POC to establish that it is possible to make a simplified keyboard. This will eventually lead us into the prototype-like phase where we will need to find a way to have more columns be utilized to create a keyboard that has only 74 keyswitches on the model. Eventually for the prototype-like phase we plan on using a 3D printed case that is 14 inch width and 4-¼ inch length.

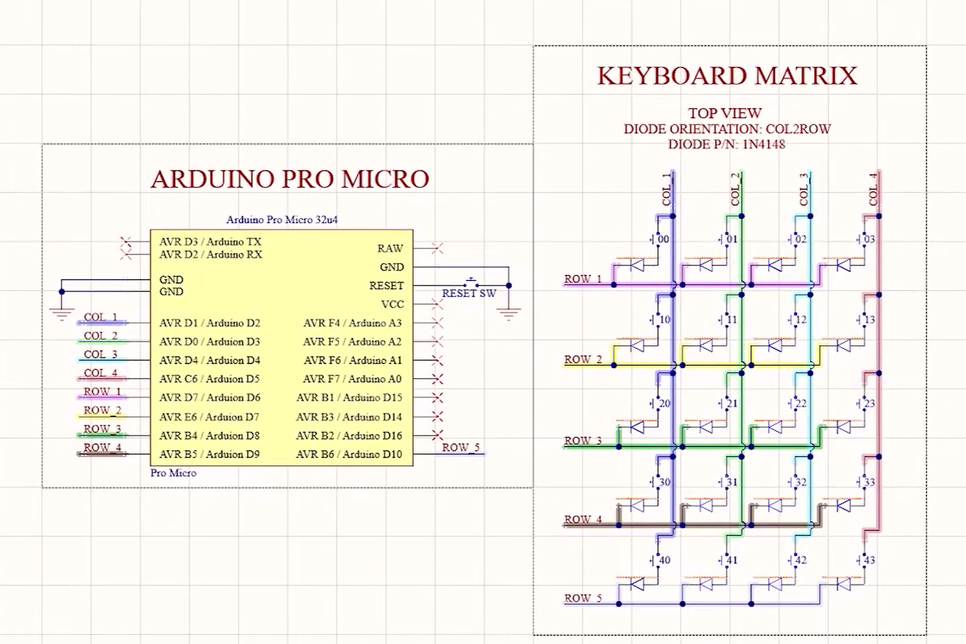
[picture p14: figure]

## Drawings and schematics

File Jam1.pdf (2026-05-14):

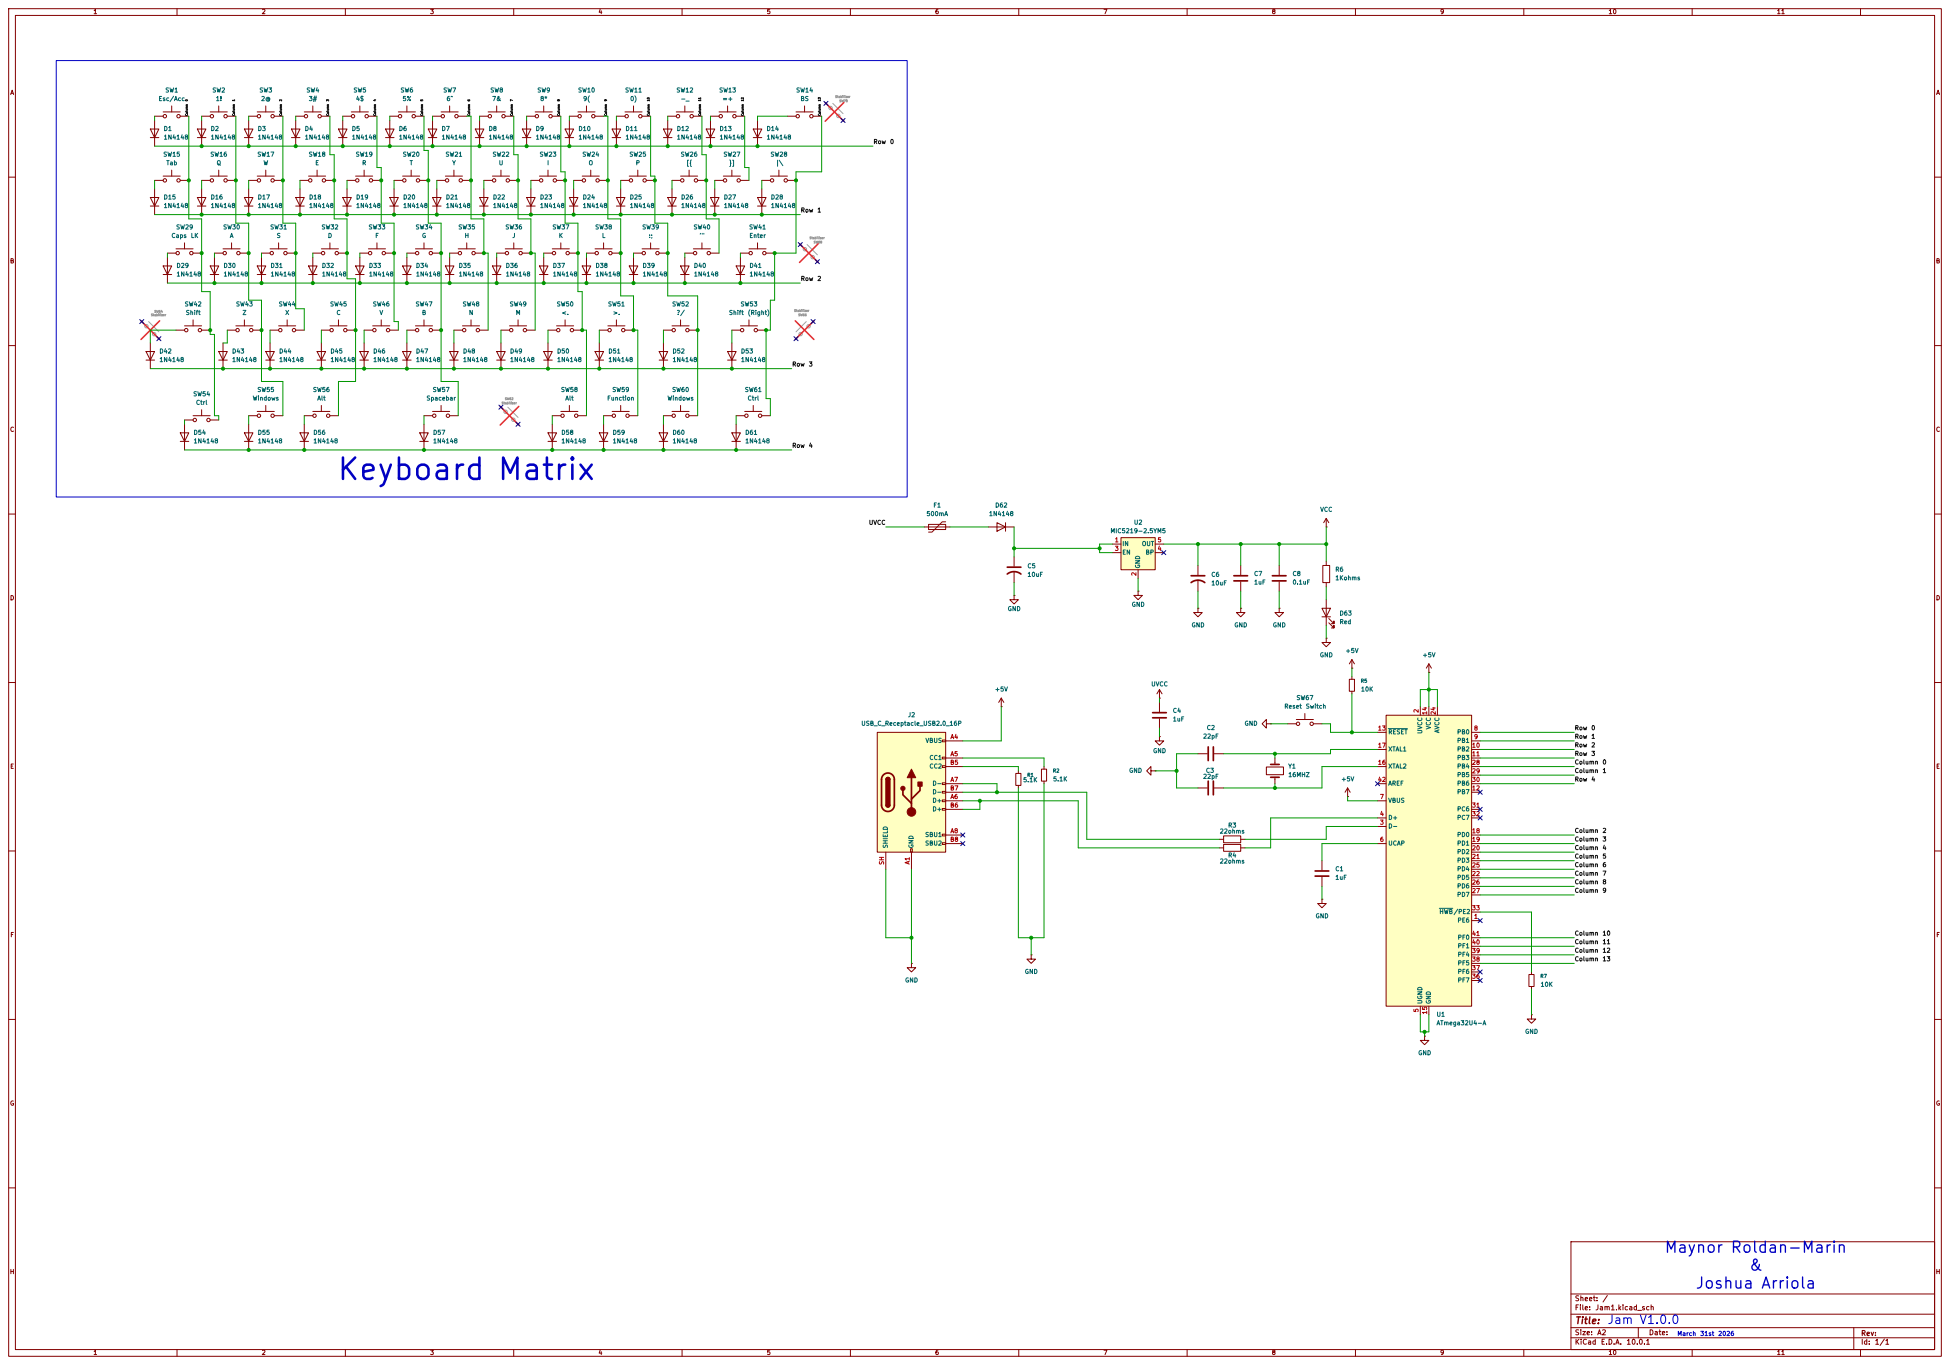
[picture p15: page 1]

Row 1 Row 2 Row 3 Row 0 Column 1 Column 0 Row 4

Column 5 Column 7 Column 4 Column 2 Column 6 Column 3 Column 8 Column 9 Column 11 Column 10 Column 13 Column 12

Size: A2 | Rev:
KiCad E.D.A. 10.0.1 | Id: 1/1

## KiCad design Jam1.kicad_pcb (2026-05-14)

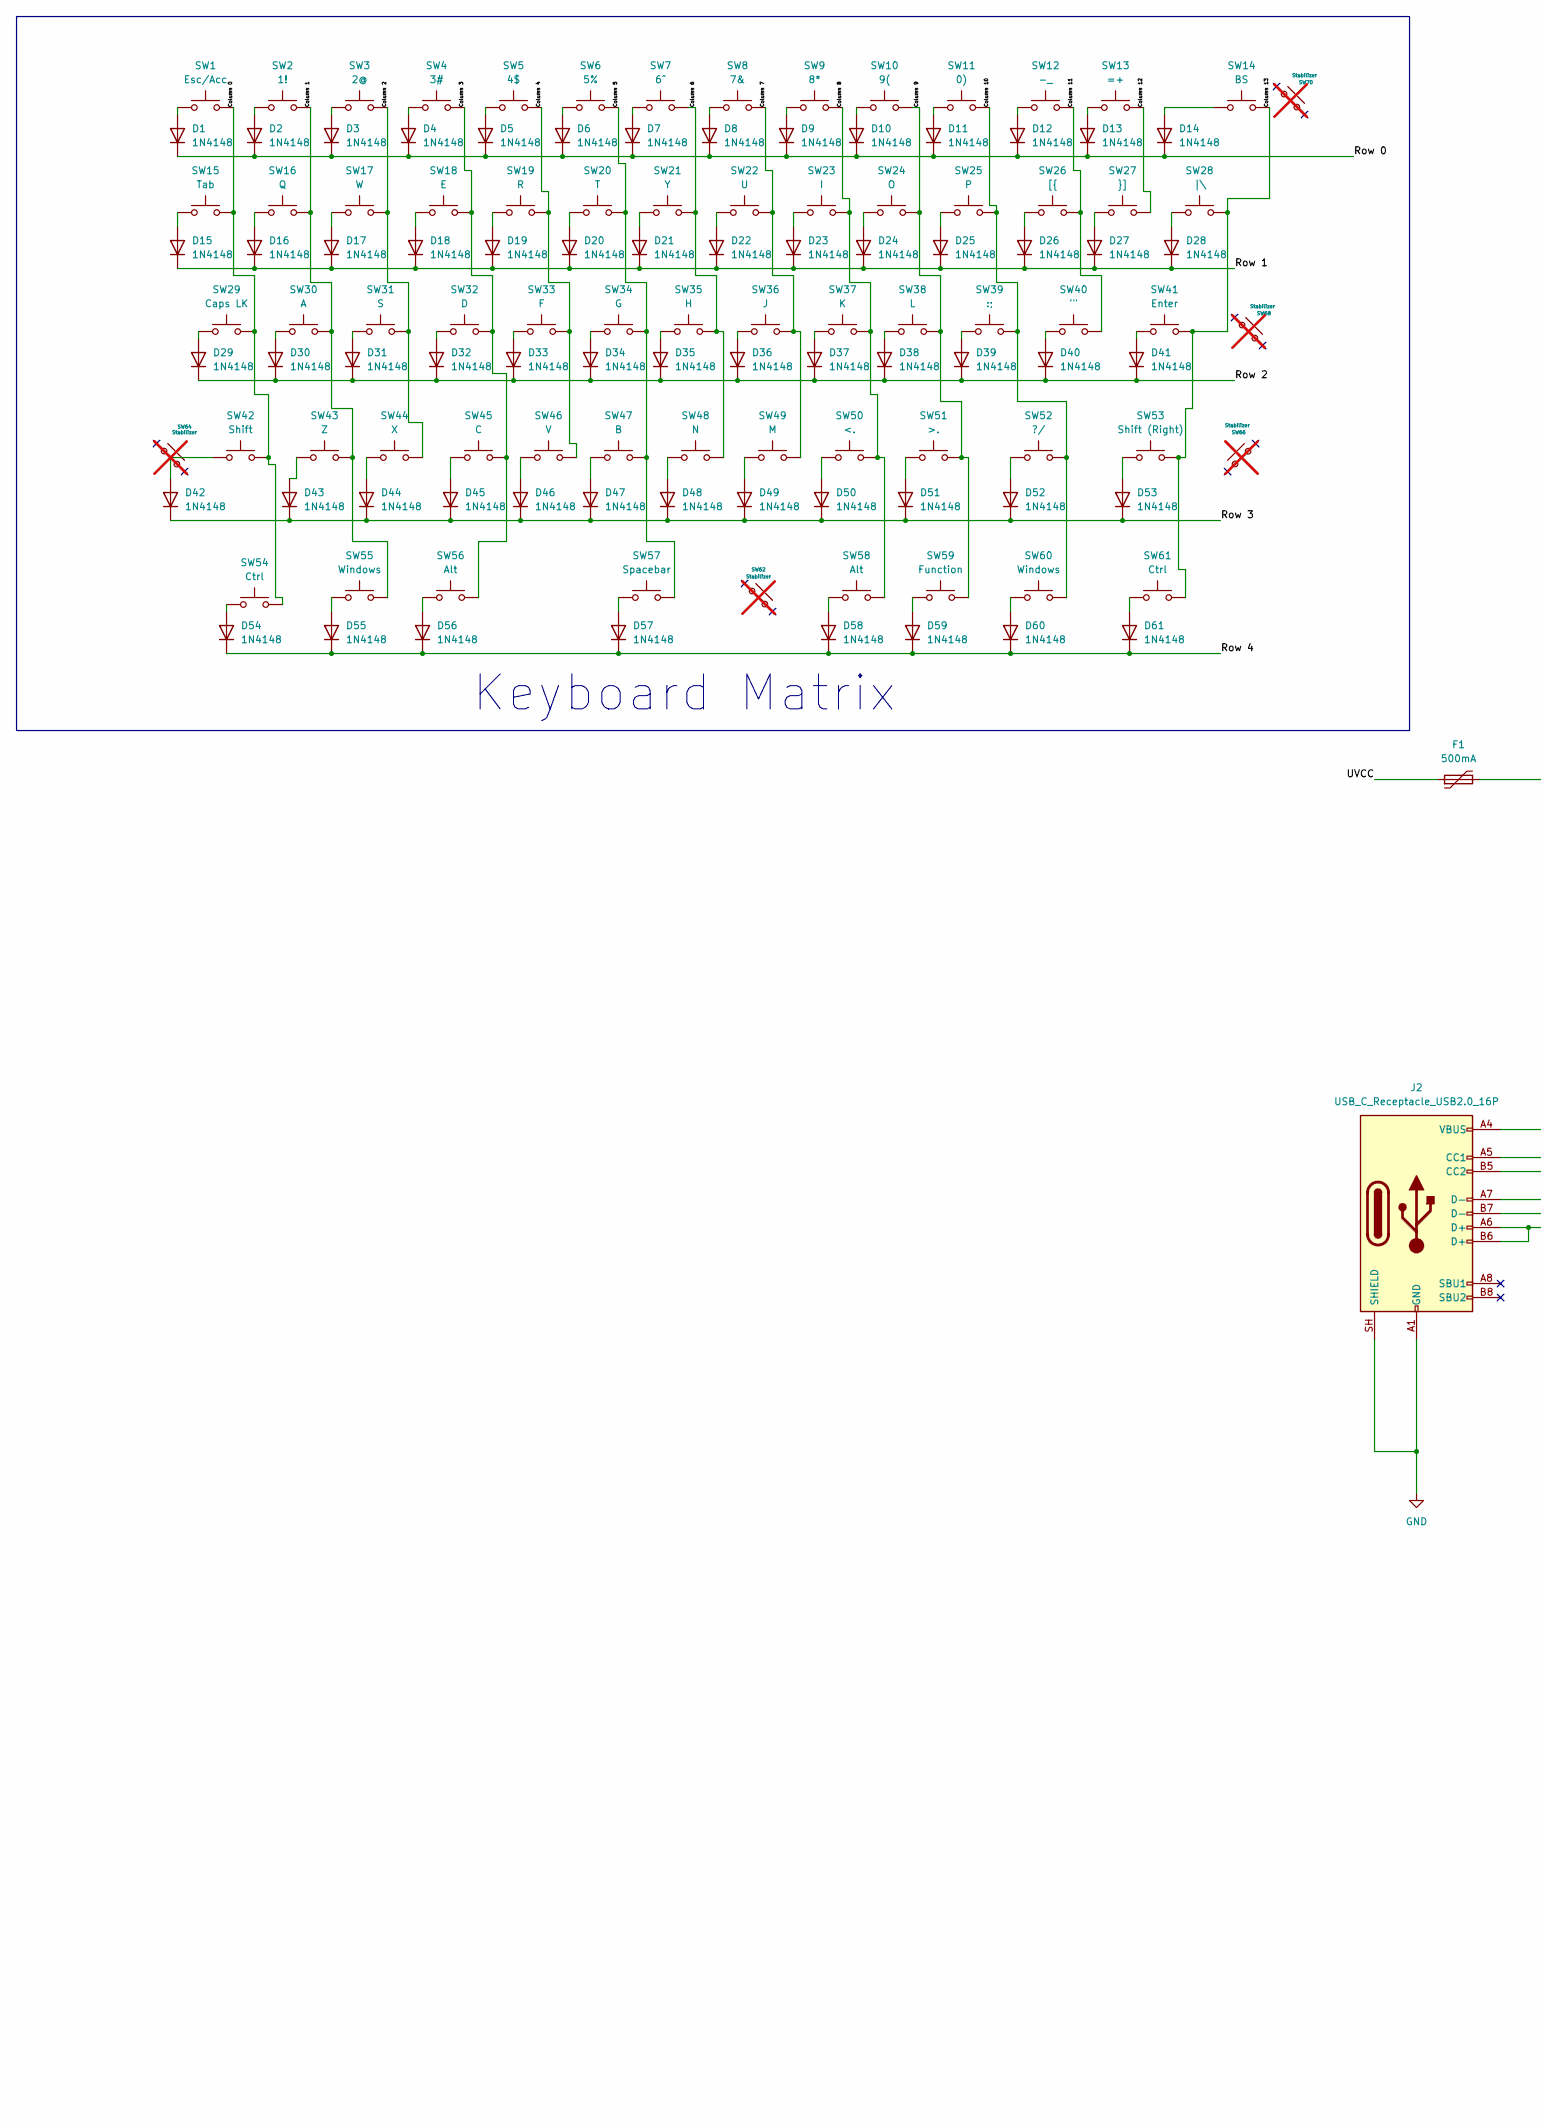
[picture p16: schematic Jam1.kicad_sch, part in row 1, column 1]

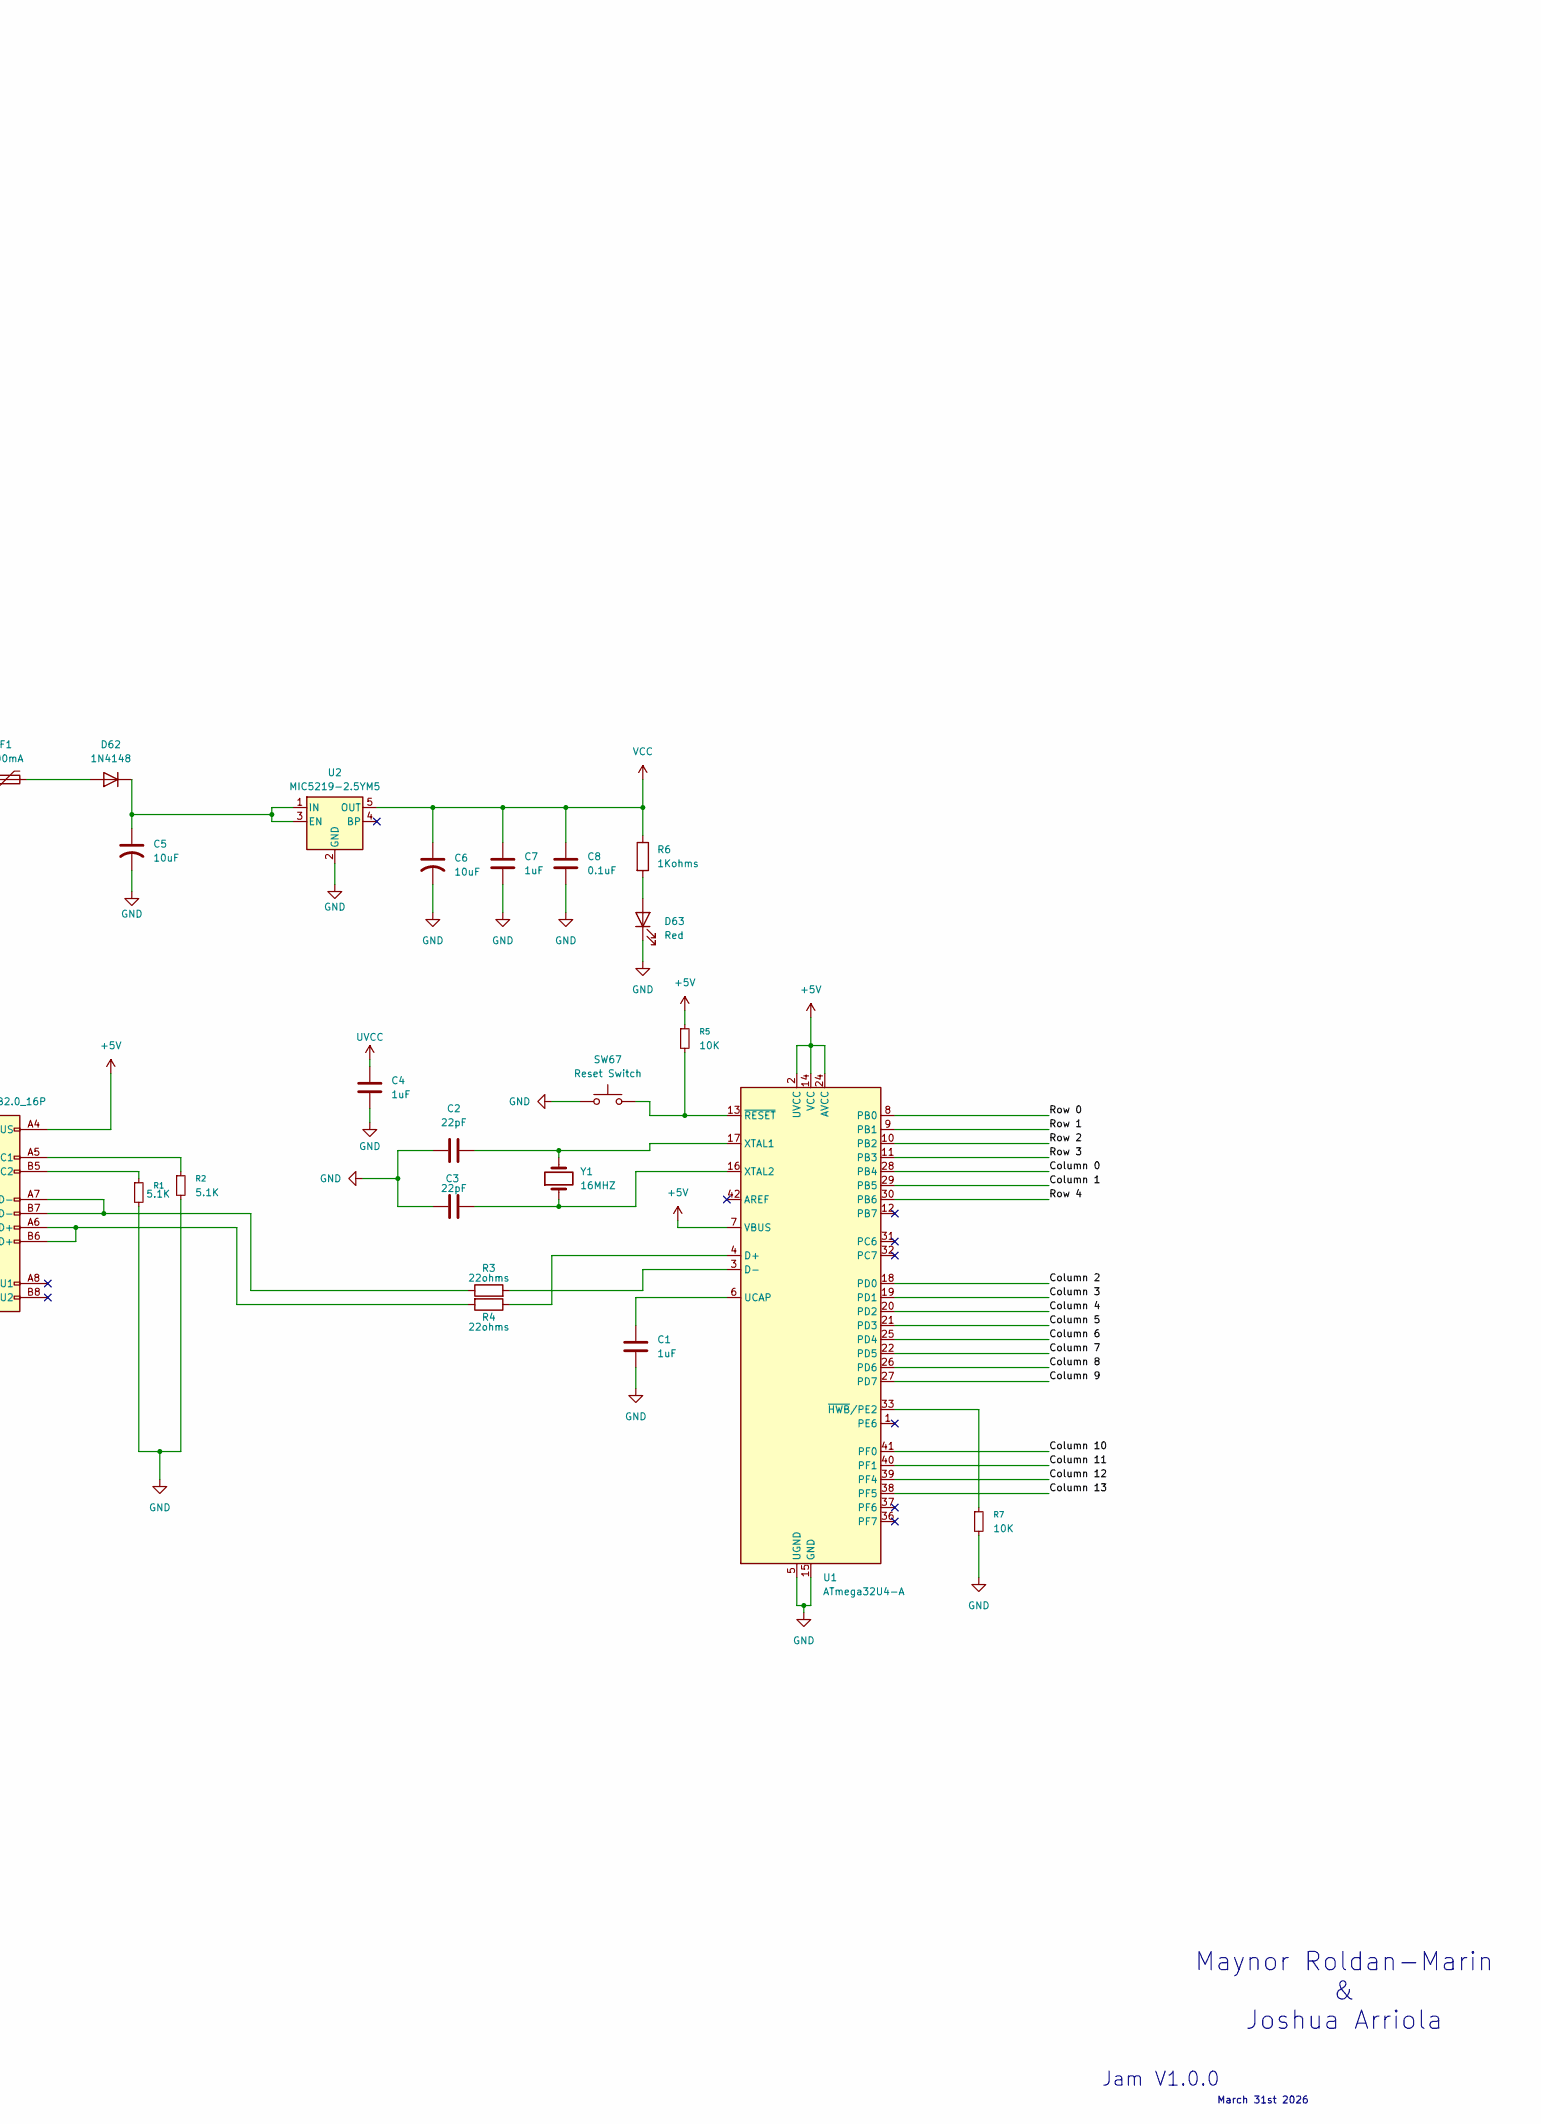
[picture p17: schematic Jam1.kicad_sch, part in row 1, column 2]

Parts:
C1, C4, C7: 1uF; C_0805_2012Metric; LCSC C28323
C2, C3: 22pF; C_0805_2012Metric; LCSC C1804
C5, C6: 10uF; C_0805_2012Metric; LCSC C380332
C8: 0.1uF; C_0805_2012Metric; LCSC C17356222
D1, D2, D3, D4, D5, D6, D7, D8, D9, D10, D11, D12, D13, D14, D15, D16, D17, D18, D19, D20, D21, D22, D23, D24, D25, D26, D27, D28, D29, D30, D31, D32, D33, D34, D35, D36, D37, D38, D39, D40, D41, D42, D43, D44, D45, D46, D47, D48, D49, D50, D51, D52, D53, D54, D55, D56, D57, D58, D59, D60, D61, D62: 1N4148; D_SOD-123; LCSC C2099
D63: Red; LED_0201_0603Metric; LCSC C9900221497
F1: 500mA; Fuse_1206_3216Metric; LCSC C20799
J2: USB_C_Receptacle_USB2.0_16P; USB_C_Receptacle_HRO_TYPE-C-31-M-12; LCSC C2927036
R1, R2: 5.1K; R_0805_2012Metric; LCSC C27834
R3, R4: 22ohms; R_0805_2012Metric; LCSC C3017752
R5, R7: 10K; R_0805_2012Metric; LCSC C17414
R6: 1Kohms; R_0805_2012Metric; LCSC C2889437
SW1: Esc/Acc; Hotswap_MX_Plated_1.00u; LCSC C2803348
SW2: 1!; Hotswap_MX_Plated_1.00u; LCSC C2803348
SW3: 2@; Hotswap_MX_Plated_1.00u; LCSC C2803348
SW4: 3#; Hotswap_MX_Plated_1.00u; LCSC C2803348
SW5: 4$; Hotswap_MX_Plated_1.00u; LCSC C2803348
SW6: 5%; Hotswap_MX_Plated_1.00u; LCSC C2803348
SW7: 6^; Hotswap_MX_Plated_1.00u; LCSC C2803348
SW8: 7&; Hotswap_MX_Plated_1.00u; LCSC C2803348
SW9: 8*; Hotswap_MX_Plated_1.00u; LCSC C2803348
SW10: 9(; Hotswap_MX_Plated_1.00u; LCSC C2803348
SW11: 0); Hotswap_MX_Plated_1.00u; LCSC C2803348
SW12: -_; Hotswap_MX_Plated_1.00u; LCSC C2803348
SW13: =+; Hotswap_MX_Plated_1.00u; LCSC C2803348
SW14: BS; Hotswap_MX_Plated_1.00u; LCSC C2803348
SW15: Tab; Hotswap_MX_Plated_1.00u; LCSC C2803348
SW16: Q; Hotswap_MX_Plated_1.00u; LCSC C2803348
SW17: W; Hotswap_MX_Plated_1.00u; LCSC C2803348
SW18: E; Hotswap_MX_Plated_1.00u; LCSC C2803348
SW19: R; Hotswap_MX_Plated_1.00u; LCSC C2803348
SW20: T; Hotswap_MX_Plated_1.00u; LCSC C2803348
SW21: Y; Hotswap_MX_Plated_1.00u; LCSC C2803348
SW22: U; Hotswap_MX_Plated_1.00u
SW23: I; Hotswap_MX_Plated_1.00u; LCSC C2803348
SW24: O; Hotswap_MX_Plated_1.00u; LCSC C2803348
SW25: P; Hotswap_MX_Plated_1.00u; LCSC C2803348
SW26: [{; Hotswap_MX_Plated_1.00u; LCSC C2803348
SW27: }]; Hotswap_MX_Plated_1.00u; LCSC C2803348
SW28: |\; Hotswap_MX_Plated_1.00u; LCSC C2803348
SW29: Caps LK; Hotswap_MX_Plated_1.00u; LCSC C2803348
SW30: A; Hotswap_MX_Plated_1.00u; LCSC C2803348
SW31: S; Hotswap_MX_Plated_1.00u; LCSC C2803348
SW32: D; Hotswap_MX_Plated_1.00u; LCSC C2803348
SW33: F; Hotswap_MX_Plated_1.00u
SW34: G; Hotswap_MX_Plated_1.00u; LCSC C2803348
SW35: H; Hotswap_MX_Plated_1.00u; LCSC C2803348
SW36: J; Hotswap_MX_Plated_1.00u; LCSC C2803348
SW37: K; Hotswap_MX_Plated_1.00u; LCSC C2803348
SW38: L; Hotswap_MX_Plated_1.00u; LCSC C2803348
SW39: :;; Hotswap_MX_Plated_1.00u; LCSC C2803348
SW40: '"; Hotswap_MX_Plated_1.00u; LCSC C2803348
SW41: Enter; Hotswap_MX_Plated_1.00u; LCSC C2803348
SW42: Shift; Hotswap_MX_Plated_1.00u; LCSC C2803348
SW43: Z; Hotswap_MX_Plated_1.00u; LCSC C2803348
SW44: X; Hotswap_MX_Plated_1.00u; LCSC C2803348
SW45: C; Hotswap_MX_Plated_1.00u; LCSC C2803348
SW46: V; Hotswap_MX_Plated_1.00u; LCSC C2803348
SW47: B; Hotswap_MX_Plated_1.00u; LCSC C2803348
SW48: N; Hotswap_MX_Plated_1.00u; LCSC C2803348
SW49: M; Hotswap_MX_Plated_1.00u; LCSC C2803348
SW50: <.; Hotswap_MX_Plated_1.00u; LCSC C2803348
SW51: >.; Hotswap_MX_Plated_1.00u; LCSC C2803348
SW52: ?/; Hotswap_MX_Plated_1.00u; LCSC C2803348
SW53: Shift (Right); Hotswap_MX_Plated_1.00u; LCSC C2803348
SW54, SW61: Ctrl; Hotswap_MX_Plated_1.00u; LCSC C2803348
SW55, SW60: Windows; Hotswap_MX_Plated_1.00u; LCSC C2803348
SW56, SW58: Alt; Hotswap_MX_Plated_1.00u; LCSC C2803348
SW57: Spacebar; Hotswap_MX_Plated_1.00u; LCSC C2803348
SW59: Function; Hotswap_MX_Plated_1.00u; LCSC C2803348
SW62: Stabilizer; Stabilizer_MX_6.25u; not fitted
SW64, SW66, SW68, SW70: Stabilizer; Stabilizer_MX_2.00u; not fitted
SW67: Reset Switch; SW_SPST_SKQG_WithStem; LCSC C2886894
U1: ATmega32U4-A; TQFP-44_10x10mm_P0.8mm; LCSC C44854
U2: MIC5219-2.5YM5; SOT-23-5; LCSC C18212648
Y1: 16MHZ; Crystal_SMD_3225-4Pin_3.2x2.5mm; LCSC C112972

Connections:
+5V: J2.A4 (VBUS), J2.A9 (VBUS), J2.B4 (VBUS), J2.B9 (VBUS), R5.1, U1.2 (UVCC), U1.7 (VBUS), U1.14 (VCC), U1.24 (AVCC), U1.34 (VCC), U1.44 (AVCC)
/Column 0: SW1.2, SW15.2, SW29.2, SW42.2, SW54.2, U1.28 (PB4)
/Column 1: SW2.2, SW16.2, SW30.2, SW43.2, SW55.2, U1.29 (PB5)
/Column 2: SW3.2, SW17.2, SW31.2, SW44.2, U1.18 (PD0)
/Column 3: SW4.2, SW18.2, SW32.2, SW45.2, SW56.2, U1.19 (PD1)
/Column 4: SW5.2, SW19.2, SW33.2, SW46.2, U1.20 (PD2)
/Column 5: SW6.2, SW20.2, SW34.2, SW47.2, SW57.2, U1.21 (PD3)
/Column 6: SW7.2, SW21.2, SW35.2, SW48.2, U1.25 (PD4)
/Column 7: SW8.2, SW22.2, SW36.2, SW49.2, U1.22 (PD5)
/Column 8: SW9.2, SW23.2, SW37.2, SW50.2, SW58.2, U1.26 (PD6)
/Column 9: SW10.2, SW24.2, SW38.2, SW51.2, SW59.2, U1.27 (PD7)
/Column 10: SW11.2, SW25.2, SW39.2, SW52.2, SW60.2, U1.41 (PF0)
/Column 11: SW12.2, SW26.2, SW40.2, U1.40 (PF1)
/Column 12: SW13.2, SW27.2, U1.39 (PF4)
/Column 13: SW14.2, SW28.2, SW41.2, SW53.2, SW61.2, U1.38 (PF5)
/Row 0: D1.1 (K), D2.1 (K), D3.1 (K), D4.1 (K), D5.1 (K), D6.1 (K), D7.1 (K), D8.1 (K), D9.1 (K), D10.1 (K), D11.1 (K), D12.1 (K), D13.1 (K), D14.1 (K), U1.8 (PB0)
/Row 1: D15.1 (K), D16.1 (K), D17.1 (K), D18.1 (K), D19.1 (K), D20.1 (K), D21.1 (K), D22.1 (K), D23.1 (K), D24.1 (K), D25.1 (K), D26.1 (K), D27.1 (K), D28.1 (K), U1.9 (PB1)
/Row 2: D29.1 (K), D30.1 (K), D31.1 (K), D32.1 (K), D33.1 (K), D34.1 (K), D35.1 (K), D36.1 (K), D37.1 (K), D38.1 (K), D39.1 (K), D40.1 (K), D41.1 (K), U1.10 (PB2)
/Row 3: D42.1 (K), D43.1 (K), D44.1 (K), D45.1 (K), D46.1 (K), D47.1 (K), D48.1 (K), D49.1 (K), D50.1 (K), D51.1 (K), D52.1 (K), D53.1 (K), U1.11 (PB3)
/Row 4: D54.1 (K), D55.1 (K), D56.1 (K), D57.1 (K), D58.1 (K), D59.1 (K), D60.1 (K), D61.1 (K), U1.30 (PB6)
GND: C1.2, C2.1, C3.1, C4.2, C5.2, C6.2, C7.2, C8.2, D63.1 (K), J2.A1 (GND), J2.A12 (GND), J2.B1 (GND), J2.B12 (GND), J2.SH (SHIELD), R1.2, R2.2, R7.2, SW67.1, U1.5 (UGND), U1.15 (GND), U1.23 (GND), U1.35 (GND), U1.43 (GND), U2.2 (GND)
unnamed: D1.2 (A), SW1.1
unnamed: D2.2 (A), SW2.1
unnamed: D3.2 (A), SW3.1
unnamed: D4.2 (A), SW4.1
unnamed: D5.2 (A), SW5.1
unnamed: D6.2 (A), SW6.1
unnamed: D7.2 (A), SW7.1
unnamed: D8.2 (A), SW8.1
unnamed: D9.2 (A), SW9.1
unnamed: D10.2 (A), SW10.1
unnamed: D11.2 (A), SW11.1
unnamed: D12.2 (A), SW12.1
unnamed: D13.2 (A), SW13.1
unnamed: D14.2 (A), SW14.1
unnamed: D15.2 (A), SW15.1
unnamed: D16.2 (A), SW16.1
unnamed: D17.2 (A), SW17.1
unnamed: D18.2 (A), SW18.1
unnamed: D19.2 (A), SW19.1
unnamed: D20.2 (A), SW20.1
unnamed: D21.2 (A), SW21.1
unnamed: D22.2 (A), SW22.1
unnamed: D23.2 (A), SW23.1
unnamed: D24.2 (A), SW24.1
unnamed: D25.2 (A), SW25.1
unnamed: D26.2 (A), SW26.1
unnamed: D27.2 (A), SW27.1
unnamed: D28.2 (A), SW28.1
unnamed: D29.2 (A), SW29.1
unnamed: D30.2 (A), SW30.1
unnamed: D31.2 (A), SW31.1
unnamed: D32.2 (A), SW32.1
unnamed: D33.2 (A), SW33.1
unnamed: D34.2 (A), SW34.1
unnamed: D35.2 (A), SW35.1
unnamed: D36.2 (A), SW36.1
unnamed: D37.2 (A), SW37.1
unnamed: D38.2 (A), SW38.1
unnamed: D39.2 (A), SW39.1
unnamed: D40.2 (A), SW40.1
unnamed: D41.2 (A), SW41.1
unnamed: D42.2 (A), SW42.1
unnamed: D43.2 (A), SW43.1
unnamed: D44.2 (A), SW44.1
unnamed: D45.2 (A), SW45.1
unnamed: D46.2 (A), SW46.1
unnamed: D47.2 (A), SW47.1
unnamed: D48.2 (A), SW48.1
unnamed: D49.2 (A), SW49.1
unnamed: D50.2 (A), SW50.1
unnamed: D51.2 (A), SW51.1
unnamed: D52.2 (A), SW52.1
unnamed: D53.2 (A), SW53.1
unnamed: D54.2 (A), SW54.1
unnamed: D55.2 (A), SW55.1
unnamed: D56.2 (A), SW56.1
unnamed: D57.2 (A), SW57.1
unnamed: D58.2 (A), SW58.1
unnamed: D59.2 (A), SW59.1
unnamed: D60.2 (A), SW60.1
unnamed: D61.2 (A), SW61.1
unnamed: D62.2 (A), F1.2
unnamed: C5.1, D62.1 (K), U2.1 (IN), U2.3 (EN)
unnamed: D63.2 (A), R6.2
unnamed: J2.A5 (CC1), R2.1
unnamed: J2.B5 (CC2), R1.1
unnamed: J2.A6 (D+), J2.B6 (D+), R4.2
unnamed: J2.A7 (D-), J2.B7 (D-), R3.1
unnamed: R4.1, U1.4 (D+)
unnamed: R3.2, U1.3 (D-)
unnamed: C1.1, U1.6 (UCAP)
unnamed: C2.2, U1.17 (XTAL1), Y1.2
unnamed: C3.2, U1.16 (XTAL2), Y1.1
unnamed: R7.1, U1.33 (~HWB/PE2)
unnamed: R5.2, SW67.2, U1.13 (~RESET)
UVCC: C4.1, F1.1
VCC: C6.1, C7.1, C8.1, R6.1, U2.5 (OUT)

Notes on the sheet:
Keyboard Matrix
March 31st 2026
Maynor Roldan-Marin & Joshua Arriola
Jam V1.0.0

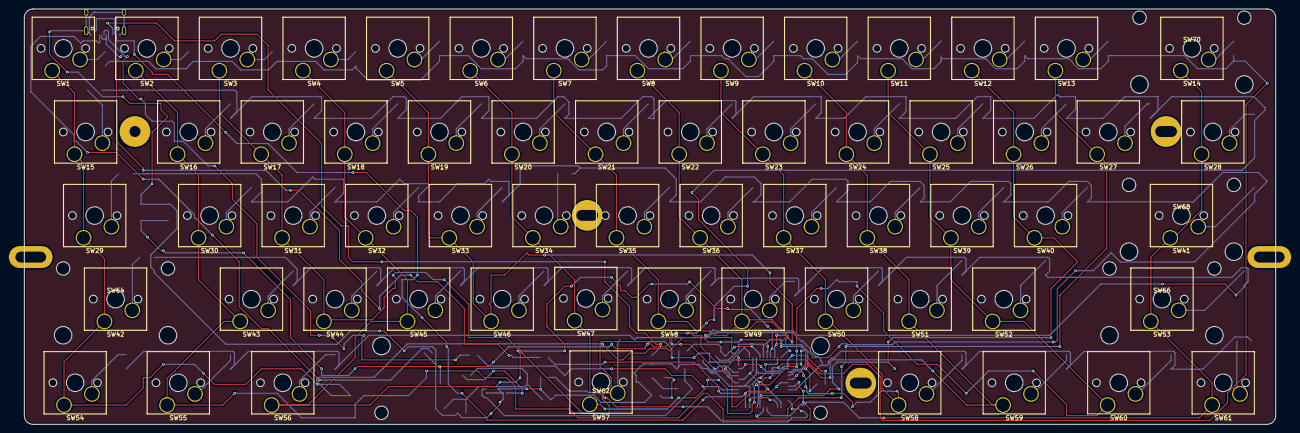
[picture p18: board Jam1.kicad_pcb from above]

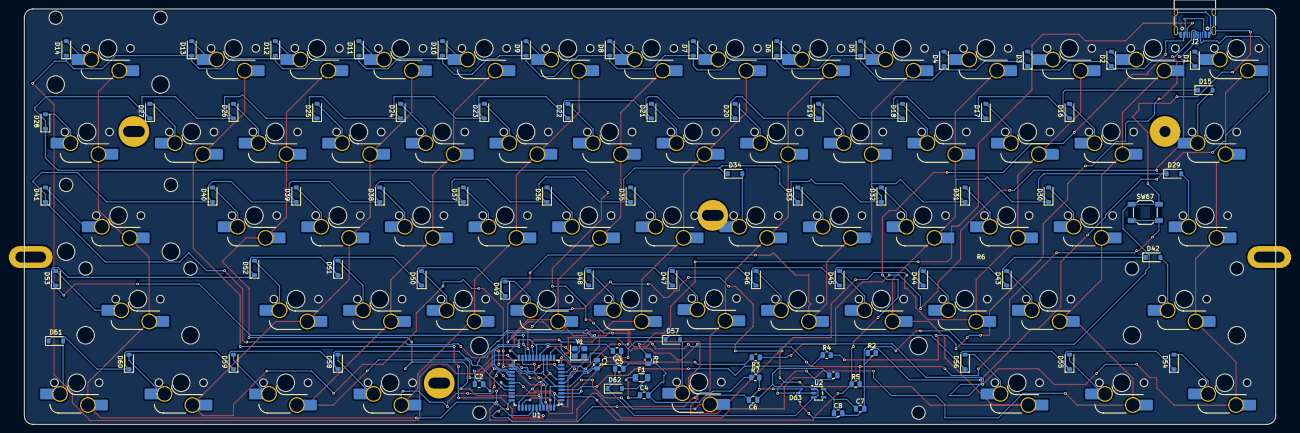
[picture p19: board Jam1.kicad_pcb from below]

Board: 2 copper layers, 285.0 x 94.6 mm, 156 parts (84 on the bottom side), 98 nets.

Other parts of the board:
HOLE: VAL**; PKRHSL
HOLE#2: VAL**; PKRHSL
HOLE#3, HOLE#4, HOLE#6: VAL**; PKRH
HOLE#5: VAL**; PKRHC

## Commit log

2026-02-10 Create Block Diagram Design
    This block diagram displays what parts are considered using in this project. As the following goes, Key switches (Kailh or cherry MX) it is possible to use Choc switches (boxed switches) but for now 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
2026-02-10 Adding LogBook of where we are currently progress
    This log book is still a work in progress, and there are still edit to be made in the future, this contains Proof of Concept phase and the soon to be Prototype-like-Phase
2026-05-14 Added both the matrix coding and remap coding
    These are the codes and mapping for our keyboard project, please not that as of now 55 keys work on the keyboard currently, we are still trying to get the other 6 keys to work with our circuit board
2026-05-14 3D Board Rendering Photo
    3D board rendering model of the top panel and bottom panel.
2026-05-14 UPDATED Logbook to keep track of changes
    This logbook kept track of our design journey, along with decisions we both had to settle on, what worked, and what did not work. We communicated with each other to discuss what parts needed to be altered and what needed replacing. It also helps us keep track of what our previous plans were, what we kept, and what we got rid of. Half of it was written by one member who was getting the components to the PCB manufacturer, which was JLC, and the other half was written by the other member while assembling the physical keyboard with extra components we needed that were not electrical.
2026-05-14 Jam61 files
    Includes all Gerber files, BOM files, Designators (manufacturer parts), Drill holes, PCB editor, and schematic, and includes all layers used in PCB editor mode
    [Jam1.csv, Jam1.kicad_pcb, Jam1.kicad_sch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]
2026-05-14 Schematic PDF plot
    This file contains the schematic PDF version, there is also the actual schematic in the repository.
2026-05-14 User Documentation
    The documents discuss what is relevant for the user to know how to use our circuit board if they plan on getting it developed by a PCB manufacturing company and describes what this circuit is capable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
2026-05-14 Testing Documents
    Discuss different ways we test our project out physically and soft ware wise, it also discuss how to go about testing the hot swappable sockets by either inserting the key switches or using conductive tweezers for each socket pin.
2026-05-14 THIS THE SOFTWARE REQUIRED TO MAP THE KEYBOARD
    This the main code you will need in order to get the circuit board working, grab this file only and use the QMK Toolbox application to upload the software into the circuit. Refer back to the user doc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
2026-05-15 Update on keyboard coding
    As of now only 54 out of the 61 keys are functioning, for some reason one of the columns is acting as if it's dead it may have to do with the way it was mapped on the matrix in kicad
2026-05-15 UPDATED Logbook to keep track of changes
    This logbook kept track of our design journey, along with decisions we both had to settle on, what worked, and what did not work. We communicated with each other to discuss what parts needed to be altered and what needed replacing. It also helps us keep track of what our previous plans were, what we kept, and what we got rid of. Half of it was written by one member who was getting the components to the PCB manufacturer, which was JLC, and the other half was written by the other member while assembling the physical keyboard with extra components we needed that were not electrical
